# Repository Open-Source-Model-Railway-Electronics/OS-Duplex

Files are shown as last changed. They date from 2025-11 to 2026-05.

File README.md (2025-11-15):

# OS-Duplex

The OS-Duplex is a dual DCC accessory decoder designed for all types of turnout drives — from traditional solenoids to motor drives and relay modules for frog polarization.  
Each side (A and B) can operate independently or be linked together.

Optional relay sockets allow you to add point frog polarization, or use the same outputs to drive extra coils or motors.

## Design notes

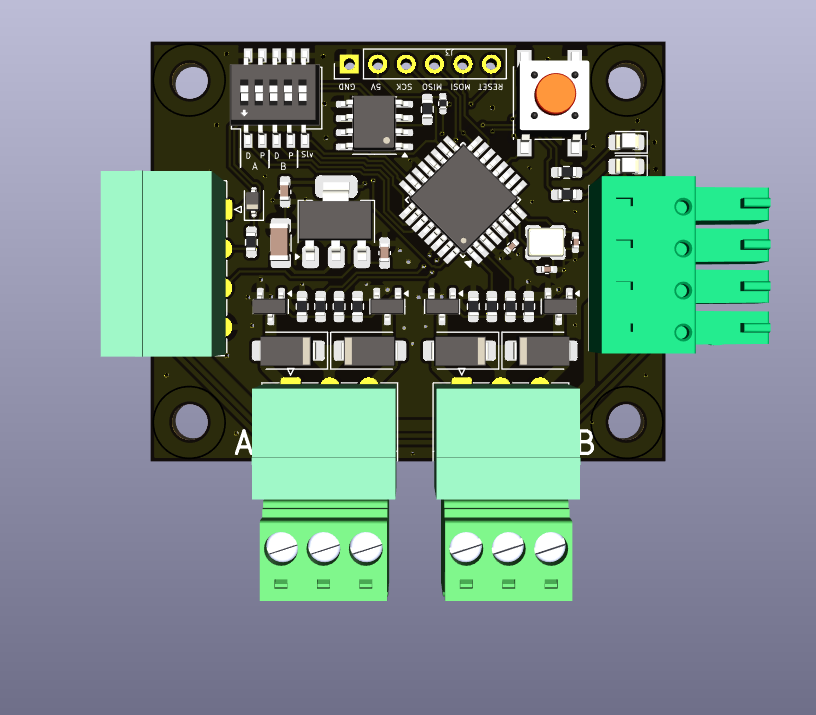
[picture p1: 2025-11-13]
hardware/OS-Duplex.png

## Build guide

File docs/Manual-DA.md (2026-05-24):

> 🌐 &nbsp; [🇬🇧 EN](Manual-EN.md) &nbsp;|&nbsp; [🇩🇪 DE](Manual-DE.md) &nbsp;|&nbsp; [🇫🇷 FR](Manual-FR.md) &nbsp;|&nbsp; [🇳🇱 NL](Manual-NL.md) &nbsp;|&nbsp; [🇪🇸 ES](Manual-ES.md) &nbsp;|&nbsp; [🇮🇹 IT](Manual-IT.md) &nbsp;|&nbsp; [🇵🇱 PL](Manual-PL.md) &nbsp;|&nbsp; [🇨🇿 CS](Manual-CS.md) &nbsp;|&nbsp; 🇩🇰 DA &nbsp;|&nbsp; [🇳🇴 NO](Manual-NO.md) &nbsp;|&nbsp; [🇸🇪 SV](Manual-SV.md) &nbsp;|&nbsp; [🇭🇺 HU](Manual-HU.md) &nbsp;|&nbsp; [🇵🇹 PT](Manual-PT.md)

# ⚙️ OS-Duplex Decoder-manual

**Dobbelt DCC-dekoder til solenoider, relæer og sporskiftemotorer**

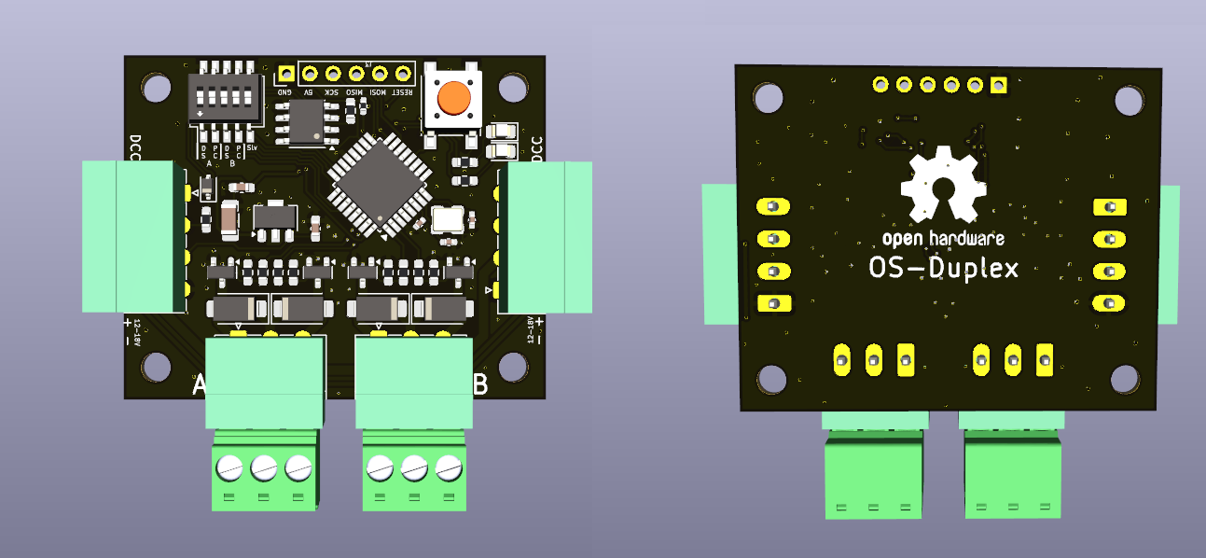
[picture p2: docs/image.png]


---

## 🔧 Introduktion

OS-Duplex er en dobbelt DCC-tilbehørsdekoder designet til alle typer sporskiftedrev — fra traditionelle solenoider til motordrev og relæmoduler til hjertestykke-polarisering.  
Hver side (A og B) kan fungere uafhængigt eller være koblet sammen.

Hver side kan fungere som enten:
- 🅰️ / 🅱️ to uafhængige enkeltudgange (hver med sin egen DCC-adresse), eller
- ⚙️ én kombineret dobbeltudgang til et toviklings- eller motordrevssporskifte.

Valgfrie relæstik giver mulighed for at tilføje sporskifte-hjertestykke-polarisering eller bruge de samme udgange til at drive ekstra spoler eller motorer.

---

## ⚡ Strømforsyning

OS-Duplex kræver en ekstern DC-strømforsyning på mellem 12 V og 18 V DC.  
⚠️ Polariteten er absolut. Overhold altid korrekte "+" og "–" forbindelser.

- Brug lavere spændinger (12 V) til sporskiftemotordrev  
- Brug højere spændinger (op til 18 V) til spoledrev

---

## 🧩 Tilslutninger

- 🔌 DCC IN – Indgang til DCC-kommandosignalet  
- ⚡ POW + / POW - – Strømindgange til hvert udgangssegment  
- ⚙️ OUT A / OUT B – Drevudgange til spoler, motorer eller relæer  
- 🔌 Gennemgangsstik – Du kan tilslutte flere Duplex-dekodere i de følgende stik  
- Du kan tilslutte op til fire relæmoduler

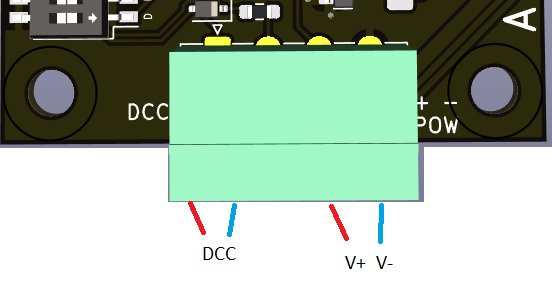
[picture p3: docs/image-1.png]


*Figur 1: Primære strømterminaler*

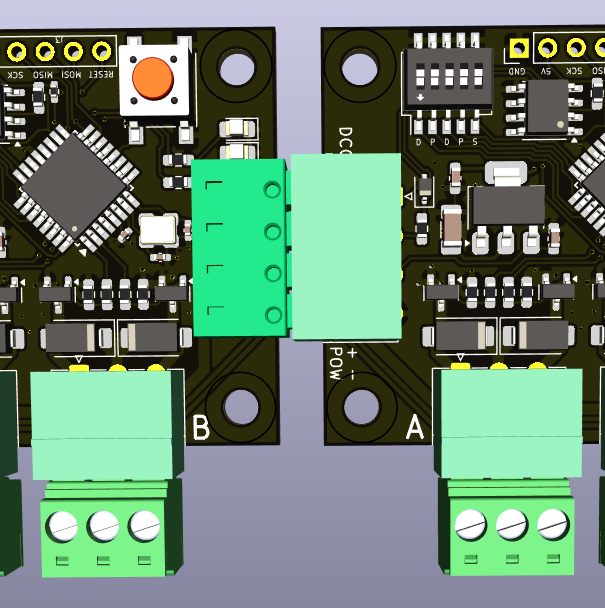
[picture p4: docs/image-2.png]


*Figur 2: 2 Duplex-dekodere kædet i serie*

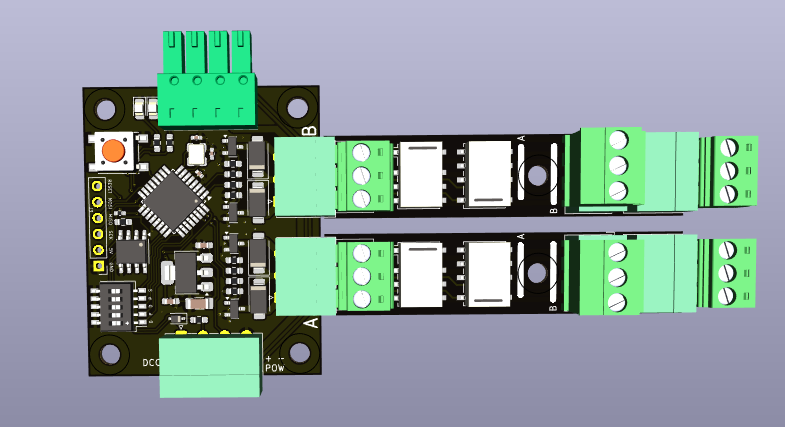
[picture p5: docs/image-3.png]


*Figur 3: 2 dobbelte relæmoduler tilsluttet*

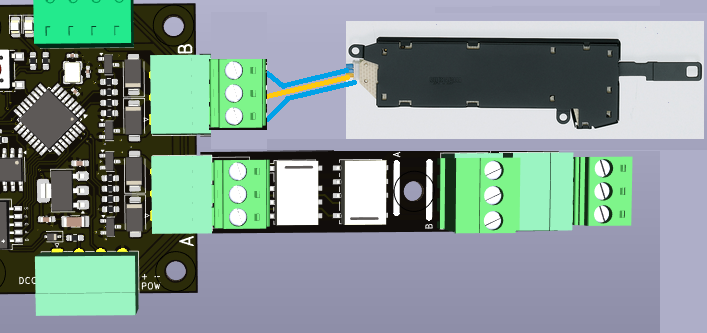
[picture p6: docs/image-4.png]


*Figur 4: Eksempel 1 — dobbelt spoledrev og dobbelt relæmodul*

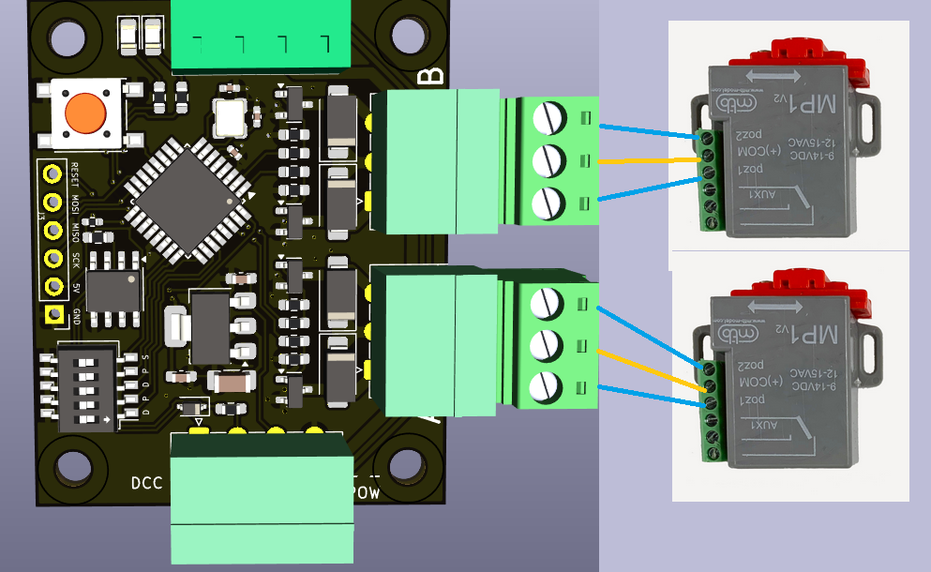
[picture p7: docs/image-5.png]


*Figur 5: Eksempel med 2x MTB MP-1*

---

## 🎚️ DIP-Switch-konfiguration

Fem DIP-switches definerer alle driftstilstande:

1️⃣ Udgang A – Tilstandsvalg: Enkelt / dobbelt udgang  
2️⃣ Udgang A – Pulstilstand: Puls (typisk spole) eller kontinuerlig (motor)  
3️⃣ Udgang B – Tilstandsvalg: Enkelt / dobbelt udgang  
4️⃣ Udgang B – Pulstilstand: Puls eller kontinuerlig  
5️⃣ Linkkontakt – Forbinder udgang B til udgang A (slavetilstand). Kun aktiv hvis A er indstillet til dobbelt tilstand

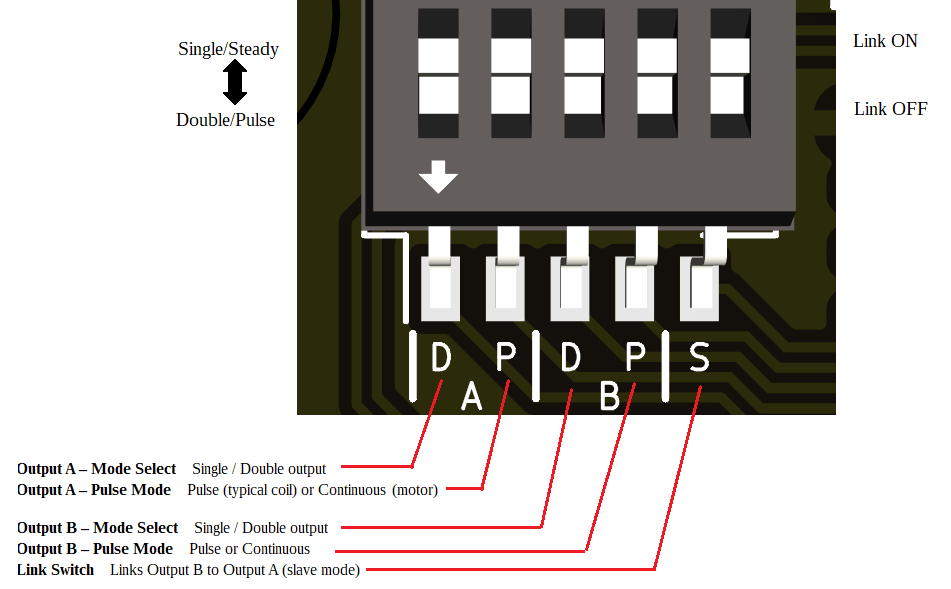
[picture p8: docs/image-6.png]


---

## ⚙️ Driftslogik

### 🅰️ Udgang A (primær)
- Fungerer som enkelt eller dobbelt udgang
- I dobbelt tilstand styrer én DCC-adresse begge udgange, uanset om de er pulset eller stabile
- I enkelt tilstand bruger hver udgang sin egen adresse

### 🅱️ Udgang B (sekundær)
- Kan køre uafhængigt som A eller som slave til A
- I koblet drift kan B automatisk håndtere hjertestykke-polarisering; det skifter relæerne og sporskiftemotoren i en bestemt rækkefølge for at forhindre kortslutninger:
    1. Afspænd hjertestykket
    2. Skift sporskiftet
    3. Genspænd hjertestykket med modsat polaritet

Denne timing understøtter Electrofrog- og Unifrog-anlæg

---

## 🔗 Slavetilstands-udvidelser

### Signaltilstand

Når linket er aktiveret mellem udgangene, ændrer udgang B adfærd afhængigt af A's tilstand:
- Hvis A er Enkelt + Puls, accepterer dekoderen DCC EXT-kommandoer til 4-lampe-signaler  
- Begge udgange fungerer sammen som en miniature-signalstyreenhed  
- OS-Duplex har ikke noget begreb om faste indstillinger, aspekter eller forindstillinger, hvad angår signaler. I stedet bruger vi DCC EXT-kommandoer, hvormed vi kan sende en værdi på 0–255 til dekoderen.

Værdien fungerer binært. 255 har den binære værdi `1111 1111`. Den høje nibble (de første 4 bits) angiver hvilke LED'er der skal blinke; den lave nibble (de sidste 4 bits) angiver hvilke lys der skal være tændt eller slukket. Når et lys er indstillet til at blinke via den høje nibble, skal den tilsvarende bit i den lave nibble være `0`. **For eksempel, når kun de første to lys skal blinke, det tredje lys er slukket, og det fjerde lys er tændt: værdien er `1100 0001` = 193 decimal.**

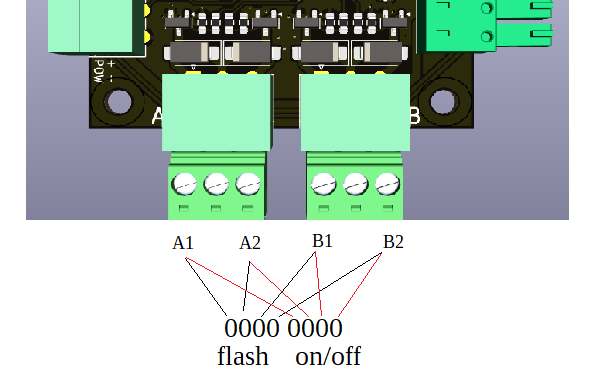
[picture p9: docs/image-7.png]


Det software, du bruger til dit modeljernbaneanlæg, skal knytte signalaspekterne til DCC EXT-værdier. Skriv den binære værdi ned for hvert ønsket aspekt og beregn derefter den decimale ækvivalent. Windows' indbyggede Lommeregner-app kan hjælpe — skift den til **Programmør**-tilstand først.

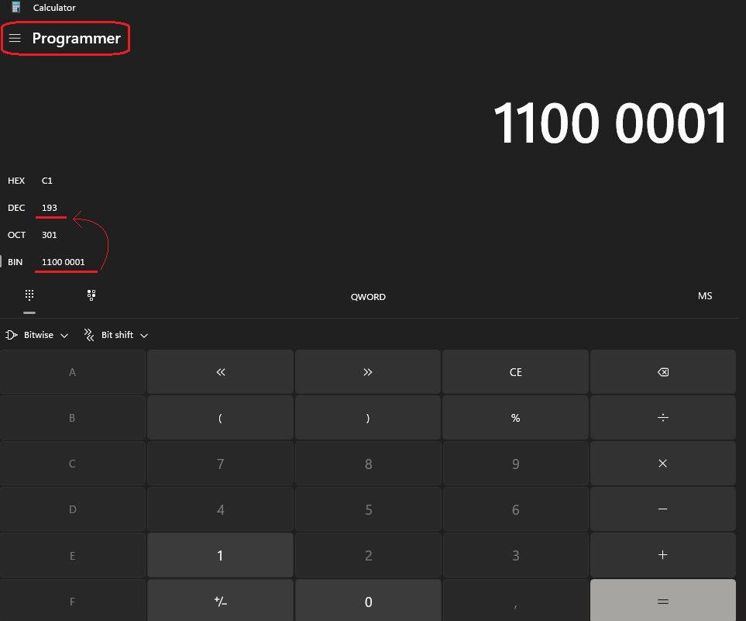
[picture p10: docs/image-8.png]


Som eksempel tager vi et hollandsk hovedlinjessignal. Vi forbinder grøn til A1, gul til A2, rød til B1 og nummerboksen til B2. Lilla er den fælles +-ledning.

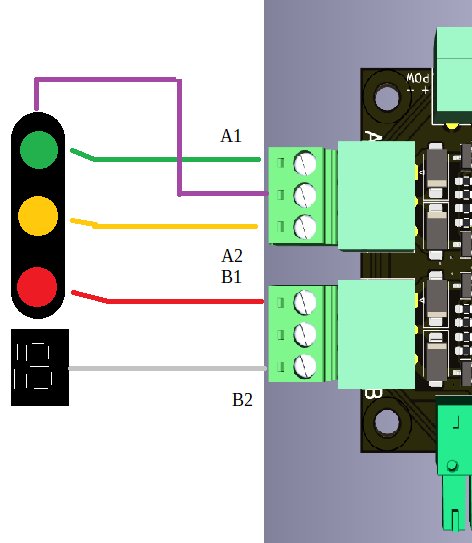
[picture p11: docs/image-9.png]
alternativ tekst


Dette signal bruger disse aspekter.

| Aspekt | Lamper (G/Y/R/W) | Høj nibble (blinkbits) | Lav nibble (tændt/slukket-bits) | Decimal |
|---|---|---|---|---|
| Stop | R | 0000 | 0100 | 4 |
| Kør | G | 0000 | 0001 | 1 |
| Forsigtig / Forvent stop | Y | 0000 | 0010 | 2 |
| Kør på sigt (Y blinker) | Y (blink) | 0010 | 0000 | 32 |
| Afvigende / hastighedsrute (G blinker) | G (blink) | 0001 | 0000 | 16 |
| Hastighed angivet ved dette signal (G blinker + W TÆNDt) | G (blink) + W TÆNDt | 0001 | 1000 | 24 |
| Tilkørsel med hastighed ved næste signal (Y + W TÆNDt) | Y TÆNDt + W TÆNDt | 0000 | 1010 | 10 |

---

## 💡 Tekniske noter

- Kompatibel med Roco, NMRA og udvidet DCC-adressering
- Hver udgang kan sikkert levere strøm til standard sporskiftespoler eller små motorer
- EEPROM gemmer seneste konfiguration og adresser
- Firmware understøtter adresseindlæring via DCC-kommando eller knapindgang (hvis implementeret)

---

## 🧰 Sikkerhed og anbefalinger

- Verificer altid korrekt forsyningspolaritet inden idriftsætning
- Overskrid ikke 18 V DC
- Sørg for tilstrækkelig afstand ved drift af fire højstrømsrelæer samtidigt
- Brug en passende DC-forsyning med strømkapacitet, der matcher din sporskiftetype

---

## Bilag A: DIP-switch-kombinationer

### Individuelle udgange        

| DIP-switches | Beskrivelse |
|---|---|
| 00000 | A = Dobbelt puls, B = Dobbelt puls |
| 00010 | A = Dobbelt puls, B = Dobbelt stabil |
| 00110 | A = Dobbelt puls, B = Enkelt stabil |
| 01000 | A = Dobbelt stabil, B = Dobbelt puls |
| 01010 | A = Dobbelt stabil, B = Dobbelt stabil |
| 01110 | A = Dobbelt stabil, B = Enkelt stabil |
| 11000 | A = Enkelt stabil, B = Dobbelt puls |
| 11010 | A = Enkelt stabil, B = Dobbelt stabil |
| 11110 | A = Enkelt stabil, B = Enkelt stabil |

### Udgang B koblet til udgang A

| DIP-switches | Beskrivelse |
|---|---|
| 00001 | A = Dobbelt puls, B = Dobbelt relæ |
| 00101 | A = Dobbelt puls, B = Enkelt relæ |
| 01001 | A = Dobbelt stabil, B = Dobbelt relæ |
| 01101 | A = Dobbelt stabil, B = Enkelt relæ |
| 10001 | Signaltilstand |

---

📘 *Slutning på manual*

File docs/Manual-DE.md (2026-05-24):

> 🌐 &nbsp; [🇬🇧 EN](Manual-EN.md) &nbsp;|&nbsp; 🇩🇪 DE &nbsp;|&nbsp; [🇫🇷 FR](Manual-FR.md) &nbsp;|&nbsp; [🇳🇱 NL](Manual-NL.md) &nbsp;|&nbsp; [🇪🇸 ES](Manual-ES.md) &nbsp;|&nbsp; [🇮🇹 IT](Manual-IT.md) &nbsp;|&nbsp; [🇵🇱 PL](Manual-PL.md) &nbsp;|&nbsp; [🇨🇿 CS](Manual-CS.md) &nbsp;|&nbsp; [🇩🇰 DA](Manual-DA.md) &nbsp;|&nbsp; [🇳🇴 NO](Manual-NO.md) &nbsp;|&nbsp; [🇸🇪 SV](Manual-SV.md) &nbsp;|&nbsp; [🇭🇺 HU](Manual-HU.md) &nbsp;|&nbsp; [🇵🇹 PT](Manual-PT.md)

# ⚙️ OS-Duplex Decoder Handbuch

**Dualer DCC-Decoder für Magnetartikel, Relais und Weichenmotoren**



---

## 🔧 Einführung

Der OS-Duplex ist ein dualer DCC-Zubehördecoder für alle Arten von Weichenantrieben — von traditionellen Magnetartikeln über Motorantriebe bis hin zu Relaismodulen für die Herzstück-Polarisierung.  
Jede Seite (A und B) kann unabhängig betrieben oder miteinander verbunden werden.

Jede Seite kann entweder als:
- 🅰️ / 🅱️ zwei unabhängige Einzelausgänge (jeweils mit eigener DCC-Adresse), oder
- ⚙️ ein kombinierter Doppelausgang für einen Doppelspulen- oder Motorantrieb-Weiche

fungieren.

Optionale Relais-Sockel ermöglichen die Herzstück-Polarisierung oder den Betrieb zusätzlicher Spulen oder Motoren über dieselben Ausgänge.

---

## ⚡ Stromversorgung

Der OS-Duplex benötigt eine externe DC-Stromversorgung zwischen 12 V und 18 V DC.  
⚠️ Die Polarität ist absolut. Beachte stets die korrekte „+" und „–" Verbindung.

- Niedrigere Spannungen (12 V) für Motorantriebe verwenden  
- Höhere Spannungen (bis 18 V) für Magnetartikelantriebe verwenden

---

## 🧩 Anschlüsse

- 🔌 DCC IN – Eingang für das DCC-Befehlssignal  
- ⚡ POW + / POW - – Stromversorgungseingänge für jeden Ausgangsbereich  
- ⚙️ OUT A / OUT B – Antriebsausgänge für Spulen, Motoren oder Relais  
- 🔌 Durchschleif-Stecker – Weitere Duplex-Decoder können in die folgenden Buchsen gesteckt werden  
- Es können bis zu vier Relaismodule eingesteckt werden



*Abbildung 1: Hauptstromklemmen*



*Abbildung 2: 2 in Reihe geschaltete Duplex-Decoder*



*Abbildung 3: 2 doppelte Relaismodule eingesteckt*



*Abbildung 4: Beispiel 1 Doppelspulenantrieb und doppeltes Relaismodul*



*Abbildung 5: Beispiel mit 2x MTB MP-1*

---

## 🎚️ DIP-Schalter-Konfiguration

Fünf DIP-Schalter definieren alle Betriebsmodi:

1️⃣ Ausgang A – Modusauswahl: Einzel- / Doppelausgang  
2️⃣ Ausgang A – Impulsmodus: Impuls (typisch für Spule) oder Dauerbetrieb (Motor)  
3️⃣ Ausgang B – Modusauswahl: Einzel- / Doppelausgang  
4️⃣ Ausgang B – Impulsmodus: Impuls oder Dauerbetrieb  
5️⃣ Verbindungsschalter – Verbindet Ausgang B mit Ausgang A (Slave-Modus). Nur aktiv, wenn A auf Doppelmodus eingestellt ist



---

## ⚙️ Betriebslogik

### 🅰️ Ausgang A (Primär)
- Funktioniert als Einzel- oder Doppelausgang
- Im Doppelmodus steuert eine DCC-Adresse beide Ausgänge, egal ob gepulst oder dauerhaft
- Im Einzelmodus verwendet jeder Ausgang seine eigene Adresse

### 🅱️ Ausgang B (Sekundär)
- Kann wie A unabhängig betrieben oder als Slave zu A betrieben werden
- Im verbundenen Betrieb kann B die Herzstück-Polarisierung automatisch übernehmen; er schaltet die Relais und den Weichenmotor in einer bestimmten Reihenfolge, um Kurzschlüsse zu vermeiden:
    1. Herzstück stromlos schalten
    2. Weiche stellen
    3. Herzstück mit umgekehrter Polarität wieder bestromen

Diese Schaltsequenz unterstützt Electrofrog- und Unifrog-Anlagen

---

## 🔗 Slave-Modus-Erweiterungen

### Signalmodus

Wenn die Verbindung zwischen den Ausgängen aktiviert ist, ändert Ausgang B sein Verhalten abhängig vom Modus von A:
- Wenn A Einzel + Impuls ist, akzeptiert der Decoder DCC EXT-Befehle für 4-Lampen-Signale  
- Beide Ausgänge agieren zusammen als miniaturisierter Signalregler  
- Der Duplex hat kein Konzept von festen Einstellungen, Begriffen oder Voreinstellungen für Signale. Stattdessen werden DCC EXT-Befehle verwendet, mit denen ein Wert von 0–255 an den Decoder übertragen werden kann.

Der Wert funktioniert binär. 255 hat den Binärwert `1111 1111`. Das obere Halbbyte (erste 4 Bits) gibt an, welche LEDs blinken sollen; das untere Halbbyte (letzte 4 Bits) gibt an, welche Lichter ein- oder ausgeschaltet sein sollen. Wenn ein Licht über das obere Halbbyte auf Blinken gesetzt wird, muss das entsprechende Bit im unteren Halbbyte `0` sein. **Wenn beispielsweise nur die ersten beiden Lichter blinken sollen, das dritte Licht aus und das vierte Licht an ist: Der Wert lautet `1100 0001` = 193 dezimal.**



Die Software, die du für deine Modellbahnanlage verwendest, muss die Signalbegriffe mit DCC EXT-Werten verknüpfen. Notiere den Binärwert für jeden gewünschten Begriff und berechne dann das Dezimaläquivalent. Der eingebaute Taschenrechner von Windows kann dabei helfen — stelle ihn zuerst in den **Programmierer**-Modus um.



Als Beispiel nehmen wir ein niederländisches Hauptstreckensignal. Wir verbinden Grün mit A1, Gelb mit A2, Rot mit B1 und den Nummernkasten mit B2. Lila ist die gemeinsame +-Leitung.



Dieses Signal verwendet folgende Begriffe:

| Begriff | Lampen (G/Y/R/W) | Oberes Halbbyte (Blinkbits) | Unteres Halbbyte (Ein/Aus-Bits) | Dezimal |
|---|---|---|---|---|
| Halt | R | 0000 | 0100 | 4 |
| Fahrt | G | 0000 | 0001 | 1 |
| Langsamfahrt / Halt erwarten | Y | 0000 | 0010 | 2 |
| Fahrt auf Sicht (Y blinkend) | Y (blink) | 0010 | 0000 | 32 |
| Abweichende Fahrt / Geschwindigkeitsroute (G blinkend) | G (blink) | 0001 | 0000 | 16 |
| Geschwindigkeit am Signal angezeigt (G blinkend + W EIN) | G (blink) + W EIN | 0001 | 1000 | 24 |
| Heranfahren mit Geschwindigkeit am nächsten Signal (Y + W EIN) | Y EIN + W EIN | 0000 | 1010 | 10 |

---

## 💡 Technische Hinweise

- Kompatibel mit Roco-, NMRA- und erweiterter DCC-Adressierung
- Jeder Ausgang kann standardmäßige Weichenspulen oder kleine Motoren sicher versorgen
- EEPROM speichert die letzte Konfiguration und Adressen
- Firmware unterstützt Adress-Einlernen per DCC-Befehl oder Taste (sofern implementiert)

---

## 🧰 Sicherheit & Empfehlungen

- Stets die korrekte Versorgungspolärität prüfen, bevor die Stromversorgung eingeschaltet wird
- 18 V DC nicht überschreiten
- Ausreichend Abstand einhalten, wenn vier Hochstromrelais gleichzeitig betrieben werden
- Ein geeignetes DC-Netzteil mit ausreichender Stromkapazität für den jeweiligen Weichentyp verwenden

---

## Anhang A, DIP-Schalter-Kombinationen

### Individuelle Ausgänge

| DIP-Schalter | Beschreibung |
|---|---|
| 00000 | A = Doppelimpuls, B = Doppelimpuls |
| 00010 | A = Doppelimpuls, B = Doppeldauerbetrieb |
| 00110 | A = Doppelimpuls, B = Einzeldauerbetrieb |
| 01000 | A = Doppeldauerbetrieb, B = Doppelimpuls |
| 01010 | A = Doppeldauerbetrieb, B = Doppeldauerbetrieb |
| 01110 | A = Doppeldauerbetrieb, B = Einzeldauerbetrieb |
| 11000 | A = Einzeldauerbetrieb, B = Doppelimpuls |
| 11010 | A = Einzeldauerbetrieb, B = Doppeldauerbetrieb |
| 11110 | A = Einzeldauerbetrieb, B = Einzeldauerbetrieb |

### Ausgang B mit Ausgang A verbunden

| DIP-Schalter | Beschreibung |
|---|---|
| 00001 | A = Doppelimpuls, B = Doppelrelais |
| 00101 | A = Doppelimpuls, B = Einzelrelais |
| 01001 | A = Doppeldauerbetrieb, B = Doppelrelais |
| 01101 | A = Doppeldauerbetrieb, B = Einzelrelais |
| 10001 | Signalmodus |

---

📘 *Ende des Handbuchs*

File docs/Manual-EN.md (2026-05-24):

> 🌐 &nbsp; 🇬🇧 EN &nbsp;|&nbsp; [🇩🇪 DE](Manual-DE.md) &nbsp;|&nbsp; [🇫🇷 FR](Manual-FR.md) &nbsp;|&nbsp; [🇳🇱 NL](Manual-NL.md) &nbsp;|&nbsp; [🇪🇸 ES](Manual-ES.md) &nbsp;|&nbsp; [🇮🇹 IT](Manual-IT.md) &nbsp;|&nbsp; [🇵🇱 PL](Manual-PL.md) &nbsp;|&nbsp; [🇨🇿 CS](Manual-CS.md) &nbsp;|&nbsp; [🇩🇰 DA](Manual-DA.md) &nbsp;|&nbsp; [🇳🇴 NO](Manual-NO.md) &nbsp;|&nbsp; [🇸🇪 SV](Manual-SV.md) &nbsp;|&nbsp; [🇭🇺 HU](Manual-HU.md) &nbsp;|&nbsp; [🇵🇹 PT](Manual-PT.md)

# ⚙️ OS-Duplex Decoder Manual

**Dual DCC decoder for solenoids, relays and turnout motors**



---

## 🔧 Introduction

The OS-Duplex is a dual DCC accessory decoder designed for all types of turnout drives — from traditional solenoids to motor drives and relay modules for frog polarization.  
Each side (A and B) can operate independently or be linked together.

Every side can act as either:
- 🅰️ / 🅱️ two independent single outputs (each with its own DCC address), or
- ⚙️ one combined double output for a twin-coil or motor drive turnout.

Optional relay sockets allow you to add point frog polarization, or use the same outputs to drive extra coils or motors.

---

## ⚡ Power Supply

The OS-Duplex requires an external DC power supply between 12 V and 18 V DC.  
⚠️ The polarity is absolute. Always observe correct “+” and “–” connections.

- Use lower voltages (12 V) for point motor drives  
- Use higher voltages (up to 18 V) for coil drives

---

## 🧩 Connections

- 🔌 DCC IN – Input for the DCC command signal  
- ⚡ POW + / POW - – Power inputs for each output section  
- ⚙️ OUT A / OUT B – Drive outputs for coils, motors, or relays  
- 🔌 Pass-Through Connectors – You can plug in more Duplex decoders in the following sockets  
- You can plug in up to four relay modules



*Figure 1: Main power terminals*



*Figure 2: 2 Duplex decoders daisy chained*



*Figure 3: 2 double relay modules plugged in*



*Figure 4: Example 1 Double Coil Drive and Double relay module*



*Figure 5: Example with 2x MTB MP-1*

---

## 🎚️ DIP-Switch Configuration

Five DIP switches define all operating modes:

1️⃣ Output A – Mode Select: Single / Double output  
2️⃣ Output A – Pulse Mode: Pulse (typical coil) or Continuous (motor)  
3️⃣ Output B – Mode Select: Single / Double output  
4️⃣ Output B – Pulse Mode: Pulse or Continuous  
5️⃣ Link Switch – Links Output B to Output A (slave mode). Only active if A is set to Double mode



---

## ⚙️ Operating Logic

### 🅰️ Output A (Primary)
- Works as single or double output
- In double mode, one DCC address controls both output, whether they are pulsed or steady
- In single mode, each output uses its own address

### 🅱️ Output B (Secondary)
- May run independently like A or as slave to A
- In linked operation, B can automatically handle frog polarization; it switches the relays and point motor in a specific sequence to prevent shorts from occurring:
    1. De-energize frog
    2. Switch turnout
    3. Re-energize frog with opposite polarity

This timing supports Electrofrog and Uni-frog layouts

---

## 🔗 Slave Mode Extensions

### Signal mode

When the link is enabled between the outputs, Output B changes behavior depending on A’s mode:
- If A is Single + Pulse, the decoder accepts DCC Extended commands for 4-lamp signals  
- Both outputs act together as a miniature signal controller  
- The Duplex has no concept of fixed settings, aspects or pre-sets when it comes to signals. Instead we use the DCC Extended commands with which we can transmit a value of 0–255 to the decoder.

The value works in binary. 255 has a binary value of `1111 1111`. The high nibble (first 4 bits) tells which LEDs should flash; the low nibble (last 4 bits) tells which lights should be on or off. When a light is set to flash via the high nibble, the corresponding bit in the low nibble must be `0`. **For example, when only the first two lights should flash, the third light is off, and the fourth light is on: the value is `1100 0001` = 193 decimal.**



The software you use for your model railway layout needs to link the signal aspects to DCC Extended values. Write down the binary value for each desired aspect and then calculate the decimal equivalent. Windows' built-in Calculator app can help — switch it to **Programmer** mode first.



As example we take a Dutch main Line signal. We connect green to A1, yellow to A2, red to B1 and the number box to B2. Purple is the common + lead



This signal uses these aspects. 

| Aspect | Lamps (G/Y/R/W) | High nibble (flash bits) | Low nibble (on/off bits) | Decimal |
|---|---|---|---|---|
| Stop | R | 0000 | 0100 | 4 |
| Proceed | G | 0000 | 0001 | 1 |
| Caution / Expect stop | Y | 0000 | 0010 | 2 |
| Drive on sight (Y flashing) | Y (flash) | 0010 | 0000 | 32 |
| Diverging / speed route (G flashing) | G (flash) | 0001 | 0000 | 16 |
| Speed indicated at this signal (G flashing + W ON) | G (flash) + W ON | 0001 | 1000 | 24 |
| Approach with speed at next signal (Y + W ON) | Y ON + W ON | 0000 | 1010 | 10 |

---

## 💡 Technical Notes

- Compatible with Roco, NMRA, and extended DCC addressing
- Each output can safely source standard turnout coils or small motors
- EEPROM stores last configuration and addresses
- Firmware supports address learning via DCC command or button input (if implemented)

---

## 🧰 Safety & Recommendations

- Always verify correct supply polarity before powering
- Do not exceed 18 V DC
- Keep adequate spacing if driving four high-current relays simultaneously
- Use a proper DC supply with current capability matching your turnout type

---

## Appendix A, DIP switch combinations

### Individual outputs        

| Dipswitches | Description |
|---|---|
| 00000 | A = Double Pulse, B = Double Pulse |
| 00010 | A = Double Pulse, B = Double Steady |
| 00110 | A = Double Pulse, B = Single Steady |
| 01000 | A = Double Steady, B = Double Pulse |
| 01010 | A = Double Steady, B = Double Steady |
| 01110 | A = Double Steady, B = Single Steady |
| 11000 | A = Single Steady, B = Double Pulse |
| 11010 | A = Single Steady, B = Double Steady |
| 11110 | A = Single Steady, B = Single Steady |

### Output B linked to output A

| Dipswitches | Description |
|---|---|
| 00001 | A = Double Pulse, B = Double Relay |
| 00101 | A = Double Pulse, B = Single Relay |
| 01001 | A = Double Steady, B = Double Relay |
| 01101 | A = Double Steady, B = Single Relay |
| 10001 | Signal mode |

---

📘 *End of Manual*

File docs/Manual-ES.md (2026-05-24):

> 🌐 &nbsp; [🇬🇧 EN](Manual-EN.md) &nbsp;|&nbsp; [🇩🇪 DE](Manual-DE.md) &nbsp;|&nbsp; [🇫🇷 FR](Manual-FR.md) &nbsp;|&nbsp; [🇳🇱 NL](Manual-NL.md) &nbsp;|&nbsp; 🇪🇸 ES &nbsp;|&nbsp; [🇮🇹 IT](Manual-IT.md) &nbsp;|&nbsp; [🇵🇱 PL](Manual-PL.md) &nbsp;|&nbsp; [🇨🇿 CS](Manual-CS.md) &nbsp;|&nbsp; [🇩🇰 DA](Manual-DA.md) &nbsp;|&nbsp; [🇳🇴 NO](Manual-NO.md) &nbsp;|&nbsp; [🇸🇪 SV](Manual-SV.md) &nbsp;|&nbsp; [🇭🇺 HU](Manual-HU.md) &nbsp;|&nbsp; [🇵🇹 PT](Manual-PT.md)

# ⚙️ Manual del Decodificador OS-Duplex

**Decodificador DCC dual para solenoides, relés y motores de aguja**



---

## 🔧 Introducción

El OS-Duplex es un decodificador de accesorios DCC dual diseñado para todo tipo de accionamientos de agujas: desde solenoides tradicionales hasta accionamientos por motor y módulos de relé para polarización de frog.  
Cada lado (A y B) puede funcionar de forma independiente o estar vinculado entre sí.

Cada lado puede actuar como:
- 🅰️ / 🅱️ dos salidas individuales independientes (cada una con su propia dirección DCC), o
- ⚙️ una salida doble combinada para una aguja de doble bobina o accionamiento por motor.

Las tomas de relé opcionales permiten añadir polarización de frog, o usar las mismas salidas para accionar bobinas o motores adicionales.

---

## ⚡ Alimentación

El OS-Duplex requiere una fuente de alimentación DC externa de entre 12 V y 18 V DC.  
⚠️ La polaridad es absoluta. Respete siempre las conexiones correctas de "+" y "–".

- Utilice tensiones más bajas (12 V) para accionamientos por motor de aguja  
- Utilice tensiones más altas (hasta 18 V) para accionamientos por bobina

---

## 🧩 Conexiones

- 🔌 DCC IN – Entrada para la señal de comando DCC  
- ⚡ POW + / POW - – Entradas de alimentación para cada sección de salida  
- ⚙️ OUT A / OUT B – Salidas de accionamiento para bobinas, motores o relés  
- 🔌 Conectores de paso directo – Puede enchufar más decodificadores Duplex en las tomas siguientes  
- Puede enchufar hasta cuatro módulos de relé



*Figura 1: Bornes de alimentación principales*



*Figura 2: 2 decodificadores Duplex en cadena*



*Figura 3: 2 módulos de doble relé enchufados*



*Figura 4: Ejemplo 1 — Accionamiento de doble bobina y módulo de doble relé*



*Figura 5: Ejemplo con 2x MTB MP-1*

---

## 🎚️ Configuración de Microinterruptores DIP

Cinco microinterruptores DIP definen todos los modos de funcionamiento:

1️⃣ Salida A – Selección de modo: salida individual / doble  
2️⃣ Salida A – Modo de impulso: Impulso (bobina típica) o Continuo (motor)  
3️⃣ Salida B – Selección de modo: salida individual / doble  
4️⃣ Salida B – Modo de impulso: Impulso o Continuo  
5️⃣ Interruptor de enlace – Vincula la Salida B a la Salida A (modo esclavo). Solo activo si A está configurada en modo doble



---

## ⚙️ Lógica de Funcionamiento

### 🅰️ Salida A (Principal)
- Funciona como salida individual o doble
- En modo doble, una dirección DCC controla ambas salidas, ya sean por impulso o continuas
- En modo individual, cada salida usa su propia dirección

### 🅱️ Salida B (Secundaria)
- Puede funcionar de forma independiente como A o como esclava de A
- En funcionamiento enlazado, B puede gestionar automáticamente la polarización de frog; conmuta los relés y el motor de aguja en una secuencia específica para evitar cortocircuitos:
    1. Desactivar el frog
    2. Conmutar la aguja
    3. Reactivar el frog con polaridad inversa

Este temporizado es compatible con agujas Electrofrog y Unifrog

---

## 🔗 Extensiones del Modo Esclavo

### Modo de señal

Cuando el enlace entre salidas está habilitado, la Salida B cambia su comportamiento según el modo de A:
- Si A es Individual + Impulso, el decodificador acepta comandos DCC Extended para señales de 4 luces  
- Ambas salidas actúan conjuntamente como un controlador de señal en miniatura  
- El Duplex no tiene concepto de ajustes fijos, aspectos o preajustes en lo referente a señales. En su lugar se utilizan los comandos DCC Extended con los que se puede transmitir un valor de 0 a 255 al decodificador.

El valor funciona en binario. 255 tiene un valor binario de `1111 1111`. El nibble alto (primeros 4 bits) indica qué LED deben parpadear; el nibble bajo (últimos 4 bits) indica qué luces deben estar encendidas o apagadas. Cuando una luz se configura para parpadear mediante el nibble alto, el bit correspondiente en el nibble bajo debe ser `0`. **Por ejemplo, cuando solo las dos primeras luces deben parpadear, la tercera luz está apagada y la cuarta luz está encendida: el valor es `1100 0001` = 193 en decimal.**



El software que utilice para su maqueta de ferrocarril debe vincular los aspectos de señal con los valores DCC Extended. Anote el valor binario de cada aspecto deseado y calcule su equivalente decimal. La aplicación Calculadora integrada en Windows puede ayudar — cámbiela primero al modo **Programador**.



Como ejemplo tomamos una señal de línea principal neerlandesa. Conectamos el verde a A1, el amarillo a A2, el rojo a B1 y el cuadro de número a B2. El morado es el conductor común +.

texto alternativo

Esta señal utiliza los siguientes aspectos.

| Aspecto | Lámparas (V/A/R/B) | Nibble alto (bits de parpadeo) | Nibble bajo (bits on/off) | Decimal |
|---|---|---|---|---|
| Parada | R | 0000 | 0100 | 4 |
| Circulación libre | G | 0000 | 0001 | 1 |
| Precaución / Espere parada | Y | 0000 | 0010 | 2 |
| Circular a la vista (Y parpadeante) | Y (parpadeo) | 0010 | 0000 | 32 |
| Desvío / ruta de velocidad (G parpadeante) | G (parpadeo) | 0001 | 0000 | 16 |
| Velocidad indicada en esta señal (G parpadeante + B encendido) | G (parpadeo) + W ON | 0001 | 1000 | 24 |
| Aproximación con velocidad en la siguiente señal (A + B encendidos) | Y ON + W ON | 0000 | 1010 | 10 |

---

## 💡 Notas Técnicas

- Compatible con direccionamiento DCC de Roco, NMRA y extendido
- Cada salida puede accionar de forma segura bobinas de aguja estándar o motores pequeños
- La EEPROM almacena la última configuración y las direcciones
- El firmware admite aprendizaje de direcciones mediante comando DCC o entrada por botón (si está implementado)

---

## 🧰 Seguridad y Recomendaciones

- Verifique siempre la polaridad correcta de la fuente antes de conectar
- No supere los 18 V DC
- Mantenga el espaciado adecuado al accionar cuatro relés de alta corriente simultáneamente
- Utilice una fuente DC adecuada con capacidad de corriente acorde al tipo de aguja

---

## Apéndice A, Combinaciones de microinterruptores DIP

### Salidas individuales        

| Microinterruptores | Descripción |
|---|---|
| 00000 | A = Impulso doble, B = Impulso doble |
| 00010 | A = Impulso doble, B = Continuo doble |
| 00110 | A = Impulso doble, B = Continuo individual |
| 01000 | A = Continuo doble, B = Impulso doble |
| 01010 | A = Continuo doble, B = Continuo doble |
| 01110 | A = Continuo doble, B = Continuo individual |
| 11000 | A = Continuo individual, B = Impulso doble |
| 11010 | A = Continuo individual, B = Continuo doble |
| 11110 | A = Continuo individual, B = Continuo individual |

### Salida B vinculada a salida A

| Microinterruptores | Descripción |
|---|---|
| 00001 | A = Impulso doble, B = Relé doble |
| 00101 | A = Impulso doble, B = Relé individual |
| 01001 | A = Continuo doble, B = Relé doble |
| 01101 | A = Continuo doble, B = Relé individual |
| 10001 | Modo de señal |

---

📘 *Fin del Manual*

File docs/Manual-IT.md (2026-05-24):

> 🌐 &nbsp; [🇬🇧 EN](Manual-EN.md) &nbsp;|&nbsp; [🇩🇪 DE](Manual-DE.md) &nbsp;|&nbsp; [🇫🇷 FR](Manual-FR.md) &nbsp;|&nbsp; [🇳🇱 NL](Manual-NL.md) &nbsp;|&nbsp; [🇪🇸 ES](Manual-ES.md) &nbsp;|&nbsp; 🇮🇹 IT &nbsp;|&nbsp; [🇵🇱 PL](Manual-PL.md) &nbsp;|&nbsp; [🇨🇿 CS](Manual-CS.md) &nbsp;|&nbsp; [🇩🇰 DA](Manual-DA.md) &nbsp;|&nbsp; [🇳🇴 NO](Manual-NO.md) &nbsp;|&nbsp; [🇸🇪 SV](Manual-SV.md) &nbsp;|&nbsp; [🇭🇺 HU](Manual-HU.md) &nbsp;|&nbsp; [🇵🇹 PT](Manual-PT.md)

# ⚙️ Manuale OS-Duplex Decoder

**Decoder DCC doppio per solenoidi, relè e motori di scambio**



---

## 🔧 Introduzione

L'OS-Duplex è un decoder DCC per accessori a doppio canale progettato per tutti i tipi di azionamento degli scambi — dai tradizionali solenoidi ai motori e ai moduli relè per la polarizzazione del frog.  
Ogni canale (A e B) può funzionare in modo indipendente o essere collegato all'altro.

Ogni canale può operare come:
- 🅰️ / 🅱️ due uscite singole indipendenti (ciascuna con il proprio indirizzo DCC), oppure
- ⚙️ un'unica uscita doppia combinata per uno scambio a doppia bobina o a motore.

I connettori relè opzionali consentono di aggiungere la polarizzazione del frog dello scambio, oppure di usare le stesse uscite per azionare bobine o motori aggiuntivi.

---

## ⚡ Alimentazione

L'OS-Duplex richiede un'alimentazione DC esterna compresa tra 12 V e 18 V DC.  
⚠️ La polarità è assoluta. Rispettare sempre il corretto collegamento "+" e "–".

- Usare tensioni più basse (12 V) per i motori di scambio  
- Usare tensioni più alte (fino a 18 V) per l'azionamento delle bobine

---

## 🧩 Connessioni

- 🔌 DCC IN – Ingresso per il segnale di comando DCC  
- ⚡ POW + / POW - – Ingressi di alimentazione per ciascuna sezione di uscita  
- ⚙️ OUT A / OUT B – Uscite di azionamento per bobine, motori o relè  
- 🔌 Connettori pass-through – È possibile collegare ulteriori decoder Duplex ai connettori seguenti  
- È possibile collegare fino a quattro moduli relè



*Figura 1: Morsetti di alimentazione principali*



*Figura 2: 2 decoder Duplex collegati a cascata*



*Figura 3: 2 moduli relè doppi inseriti*



*Figura 4: Esempio 1 — Azionamento a doppia bobina e modulo relè doppio*



*Figura 5: Esempio con 2x MTB MP-1*

---

## 🎚️ Configurazione DIP-Switch

Cinque DIP switch definiscono tutte le modalità operative:

1️⃣ Uscita A – Selezione modalità: uscita singola / doppia  
2️⃣ Uscita A – Modalità impulso: impulso (tipico per bobine) o continuo (per motori)  
3️⃣ Uscita B – Selezione modalità: uscita singola / doppia  
4️⃣ Uscita B – Modalità impulso: impulso o continuo  
5️⃣ Interruttore di collegamento – Collega l'uscita B all'uscita A (modalità slave). Attivo solo se A è impostata in modalità doppia



---

## ⚙️ Logica di Funzionamento

### 🅰️ Uscita A (Principale)
- Funziona come uscita singola o doppia
- In modalità doppia, un indirizzo DCC controlla entrambe le uscite, sia con impulso che in modo stabile
- In modalità singola, ogni uscita utilizza il proprio indirizzo

### 🅱️ Uscita B (Secondaria)
- Può funzionare in modo indipendente come A, oppure come slave di A
- In modalità collegata, B può gestire automaticamente la polarizzazione del frog; commuta i relè e il motore di scambio in una sequenza specifica per evitare cortocircuiti:
    1. Disattiva il frog
    2. Commuta lo scambio
    3. Riattiva il frog con polarità inversa

Questa temporizzazione supporta impianti con Electrofrog e Unifrog

---

## 🔗 Estensioni Modalità Slave

### Modalità segnale

Quando il collegamento tra le uscite è abilitato, l'uscita B cambia comportamento in funzione della modalità di A:
- Se A è in modalità Singola + Impulso, il decoder accetta comandi DCC EXT per segnali a 4 luci  
- Entrambe le uscite agiscono insieme come un mini-controllore di segnali  
- Il Duplex non dispone di impostazioni fisse, aspetti o preset per i segnali. Si utilizzano invece i comandi DCC EXT con cui è possibile trasmettere un valore da 0 a 255 al decoder.

Il valore funziona in binario. 255 ha un valore binario di `1111 1111`. Il nibble alto (primi 4 bit) indica quali LED devono lampeggiare; il nibble basso (ultimi 4 bit) indica quali luci devono essere accese o spente. Quando una luce è impostata per lampeggiare tramite il nibble alto, il bit corrispondente nel nibble basso deve essere `0`. **Ad esempio, se solo le prime due luci devono lampeggiare, la terza luce è spenta e la quarta è accesa: il valore è `1100 0001` = 193 decimale.**



Il software utilizzato per il plastico ferroviario deve collegare gli aspetti del segnale ai valori DCC EXT. Annotare il valore binario per ciascun aspetto desiderato e calcolare l'equivalente decimale. L'applicazione Calcolatrice integrata in Windows può essere utile — prima impostare la modalità **Programmatore**.



Come esempio prendiamo un segnale olandese di linea principale. Colleghiamo il verde ad A1, il giallo ad A2, il rosso a B1 e il riquadro del numero a B2. Il viola è il filo comune +.



Questo segnale utilizza i seguenti aspetti.

| Aspetto | Luci (V/G/R/B) | Nibble alto (bit lampeggio) | Nibble basso (bit acceso/spento) | Decimale |
|---|---|---|---|---|
| Stop | R | 0000 | 0100 | 4 |
| Via libera | G | 0000 | 0001 | 1 |
| Attenzione / Aspettarsi stop | G (giallo) | 0000 | 0010 | 2 |
| Avanzare a vista (G giallo lampeggiante) | G giallo (lamp.) | 0010 | 0000 | 32 |
| Deviata / percorso a velocità ridotta (V lampeggiante) | V (lamp.) | 0001 | 0000 | 16 |
| Velocità indicata a questo segnale (V lamp. + B acceso) | V (lamp.) + B acceso | 0001 | 1000 | 24 |
| Avvicinarsi con velocità al segnale successivo (G giallo + B acceso) | G giallo + B acceso | 0000 | 1010 | 10 |

---

## 💡 Note Tecniche

- Compatibile con l'indirizzamento DCC Roco, NMRA ed esteso
- Ogni uscita può pilotare in sicurezza bobine di scambio standard o piccoli motori
- La EEPROM memorizza l'ultima configurazione e gli indirizzi
- Il firmware supporta l'acquisizione dell'indirizzo tramite comando DCC o pressione di un pulsante (se implementato)

---

## 🧰 Sicurezza e Raccomandazioni

- Verificare sempre la corretta polarità dell'alimentazione prima di accendere
- Non superare 18 V DC
- Mantenere una distanza adeguata se si azionano contemporaneamente quattro relè ad alta corrente
- Usare un'alimentatore DC adeguato con capacità di corrente corrispondente al tipo di scambio

---

## Appendice A — Combinazioni DIP switch

### Uscite individuali        

| DIP switch | Descrizione |
|---|---|
| 00000 | A = Doppio Impulso, B = Doppio Impulso |
| 00010 | A = Doppio Impulso, B = Doppio Stabile |
| 00110 | A = Doppio Impulso, B = Singolo Stabile |
| 01000 | A = Doppio Stabile, B = Doppio Impulso |
| 01010 | A = Doppio Stabile, B = Doppio Stabile |
| 01110 | A = Doppio Stabile, B = Singolo Stabile |
| 11000 | A = Singolo Stabile, B = Doppio Impulso |
| 11010 | A = Singolo Stabile, B = Doppio Stabile |
| 11110 | A = Singolo Stabile, B = Singolo Stabile |

### Uscita B collegata all'uscita A

| DIP switch | Descrizione |
|---|---|
| 00001 | A = Doppio Impulso, B = Relè Doppio |
| 00101 | A = Doppio Impulso, B = Relè Singolo |
| 01001 | A = Doppio Stabile, B = Relè Doppio |
| 01101 | A = Doppio Stabile, B = Relè Singolo |
| 10001 | Modalità segnale |

---

📘 *Fine del Manuale*

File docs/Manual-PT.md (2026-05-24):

> 🌐 &nbsp; [🇬🇧 EN](Manual-EN.md) &nbsp;|&nbsp; [🇩🇪 DE](Manual-DE.md) &nbsp;|&nbsp; [🇫🇷 FR](Manual-FR.md) &nbsp;|&nbsp; [🇳🇱 NL](Manual-NL.md) &nbsp;|&nbsp; [🇪🇸 ES](Manual-ES.md) &nbsp;|&nbsp; [🇮🇹 IT](Manual-IT.md) &nbsp;|&nbsp; [🇵🇱 PL](Manual-PL.md) &nbsp;|&nbsp; [🇨🇿 CS](Manual-CS.md) &nbsp;|&nbsp; [🇩🇰 DA](Manual-DA.md) &nbsp;|&nbsp; [🇳🇴 NO](Manual-NO.md) &nbsp;|&nbsp; [🇸🇪 SV](Manual-SV.md) &nbsp;|&nbsp; [🇭🇺 HU](Manual-HU.md) &nbsp;|&nbsp; 🇵🇹 PT

# ⚙️ Manual do Decoder OS-Duplex

**Decoder DCC duplo para solenóides, relés e motores de agulha**



---

## 🔧 Introdução

O OS-Duplex é um decoder de acessórios DCC duplo concebido para todos os tipos de accionamento de agulhas — desde solenóides tradicionais a accionamentos por motor e módulos de relé para polarização de frog.  
Cada lado (A e B) pode funcionar de forma independente ou estar ligado ao outro.

Cada lado pode actuar como:
- 🅰️ / 🅱️ duas saídas simples independentes (cada uma com o seu próprio endereço DCC), ou
- ⚙️ uma saída dupla combinada para uma agulha de bobine dupla ou accionamento por motor.

Os sockets de relé opcionais permitem adicionar a polarização de frog ou utilizar as mesmas saídas para accionar bobines ou motores adicionais.

---

## ⚡ Alimentação

O OS-Duplex requer uma fonte de alimentação DC externa entre 12 V e 18 V DC.  
⚠️ A polaridade é absoluta. Respeite sempre as ligações correctas de "+" e "–".

- Utilize tensões mais baixas (12 V) para accionamentos por motor de agulha  
- Utilize tensões mais elevadas (até 18 V) para accionamentos por bobine

---

## 🧩 Ligações

- 🔌 DCC IN – Entrada do sinal de comando DCC  
- ⚡ POW + / POW - – Entradas de alimentação para cada secção de saída  
- ⚙️ OUT A / OUT B – Saídas de accionamento para bobines, motores ou relés  
- 🔌 Conectores de passagem – É possível ligar mais decoders Duplex nos sockets seguintes  
- Podem ser ligados até quatro módulos de relé



*Figura 1: Terminais de alimentação principal*



*Figura 2: 2 decoders Duplex ligados em cadeia*



*Figura 3: 2 módulos de relé duplo ligados*



*Figura 4: Exemplo 1 — Accionamento de bobine dupla e módulo de relé duplo*



*Figura 5: Exemplo com 2× MTB MP-1*

---

## 🎚️ Configuração por DIP-Switch

Cinco DIP switches definem todos os modos de funcionamento:

1️⃣ Saída A – Selecção de modo: saída Simples / Dupla  
2️⃣ Saída A – Modo de impulso: Impulso (bobine típica) ou Contínuo (motor)  
3️⃣ Saída B – Selecção de modo: saída Simples / Dupla  
4️⃣ Saída B – Modo de impulso: Impulso ou Contínuo  
5️⃣ Interruptor de ligação – Liga a Saída B à Saída A (modo escravo). Apenas activo se A estiver configurado em modo Duplo



---

## ⚙️ Lógica de Funcionamento

### 🅰️ Saída A (Primária)
- Funciona como saída simples ou dupla
- Em modo duplo, um endereço DCC controla ambas as saídas, quer sejam pulsadas ou contínuas
- Em modo simples, cada saída utiliza o seu próprio endereço

### 🅱️ Saída B (Secundária)
- Pode funcionar de forma independente como A ou como escravo de A
- Em funcionamento ligado, B pode tratar automaticamente a polarização de frog; comuta os relés e o motor de agulha numa sequência específica para evitar curto-circuitos:
    1. Desactivar o frog
    2. Comutar a agulha
    3. Reactivar o frog com polaridade inversa

Esta temporização suporta maquetes com agulhas Electrofrog e Uni-frog

---

## 🔗 Extensões do Modo Escravo

### Modo de sinal

Quando a ligação entre as saídas está activa, a Saída B altera o seu comportamento consoante o modo de A:
- Se A estiver em modo Simples + Impulso, o decoder aceita comandos DCC EXT para sinais de 4 lâmpadas  
- Ambas as saídas funcionam em conjunto como um controlador de sinal em miniatura  
- O Duplex não tem conceito de configurações fixas, aspectos ou predefinições para sinais. Em vez disso, utilizam-se os comandos DCC EXT com os quais é possível transmitir um valor de 0–255 ao decoder.

O valor funciona em binário. 255 tem o valor binário `1111 1111`. O nibble alto (primeiros 4 bits) indica quais os LED que devem piscar; o nibble baixo (últimos 4 bits) indica quais as luzes que devem estar acesas ou apagadas. Quando uma luz está configurada para piscar pelo nibble alto, o bit correspondente no nibble baixo tem de ser `0`. **Por exemplo, quando apenas as duas primeiras luzes devem piscar, a terceira está apagada e a quarta está acesa: o valor é `1100 0001` = 193 em decimal.**



O software que utiliza para a sua maquete ferroviária precisa de associar os aspectos do sinal aos valores DCC EXT. Anote o valor binário para cada aspecto desejado e calcule depois o equivalente decimal. A Calculadora incorporada no Windows pode ajudar — mude-a para o modo **Programador**.



Como exemplo, tomamos um sinal de linha principal neerlandês. Ligamos o verde a A1, o amarelo a A2, o vermelho a B1 e o quadro numérico a B2. O roxo é o fio comum +

texto alternativo

Este sinal utiliza os seguintes aspectos.

| Aspecto | Lâmpadas (V/Am/V/B) | Nibble alto (bits de piscar) | Nibble baixo (bits aceso/apagado) | Decimal |
|---|---|---|---|---|
| Parar | V (vermelho) | 0000 | 0100 | 4 |
| Avançar | V (verde) | 0000 | 0001 | 1 |
| Precaução / Esperar paragem | Am (amarelo) | 0000 | 0010 | 2 |
| Avançar com cautela (Am a piscar) | Am (piscar) | 0010 | 0000 | 32 |
| Divergente / via de velocidade (V a piscar) | V verde (piscar) | 0001 | 0000 | 16 |
| Velocidade indicada neste sinal (V a piscar + B aceso) | V verde (piscar) + B aceso | 0001 | 1000 | 24 |
| Aproximar com velocidade no próximo sinal (Am + B aceso) | Am aceso + B aceso | 0000 | 1010 | 10 |

---

## 💡 Notas Técnicas

- Compatível com endereçamento DCC da Roco, NMRA e estendido
- Cada saída pode accionar com segurança bobines de agulha normais ou pequenos motores
- A EEPROM guarda a última configuração e os endereços
- O firmware suporta aprendizagem de endereço por comando DCC ou por botão (se implementado)

---

## 🧰 Segurança e Recomendações

- Verifique sempre a polaridade correcta da alimentação antes de ligar
- Não exceda 18 V DC
- Mantenha espaçamento adequado ao accionar quatro relés de alta corrente simultaneamente
- Utilize uma fonte DC adequada com capacidade de corrente correspondente ao tipo de agulha

---

## Apêndice A — Combinações de DIP switch

### Saídas individuais

| DIP switches | Descrição |
|---|---|
| 00000 | A = Impulso Duplo, B = Impulso Duplo |
| 00010 | A = Impulso Duplo, B = Contínuo Duplo |
| 00110 | A = Impulso Duplo, B = Contínuo Simples |
| 01000 | A = Contínuo Duplo, B = Impulso Duplo |
| 01010 | A = Contínuo Duplo, B = Contínuo Duplo |
| 01110 | A = Contínuo Duplo, B = Contínuo Simples |
| 11000 | A = Contínuo Simples, B = Impulso Duplo |
| 11010 | A = Contínuo Simples, B = Contínuo Duplo |
| 11110 | A = Contínuo Simples, B = Contínuo Simples |

### Saída B ligada à saída A

| DIP switches | Descrição |
|---|---|
| 00001 | A = Impulso Duplo, B = Relé Duplo |
| 00101 | A = Impulso Duplo, B = Relé Simples |
| 01001 | A = Contínuo Duplo, B = Relé Duplo |
| 01101 | A = Contínuo Duplo, B = Relé Simples |
| 10001 | Modo de sinal |

---

📘 *Fim do Manual*

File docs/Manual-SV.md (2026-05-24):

> 🌐 &nbsp; [🇬🇧 EN](Manual-EN.md) &nbsp;|&nbsp; [🇩🇪 DE](Manual-DE.md) &nbsp;|&nbsp; [🇫🇷 FR](Manual-FR.md) &nbsp;|&nbsp; [🇳🇱 NL](Manual-NL.md) &nbsp;|&nbsp; [🇪🇸 ES](Manual-ES.md) &nbsp;|&nbsp; [🇮🇹 IT](Manual-IT.md) &nbsp;|&nbsp; [🇵🇱 PL](Manual-PL.md) &nbsp;|&nbsp; [🇨🇿 CS](Manual-CS.md) &nbsp;|&nbsp; [🇩🇰 DA](Manual-DA.md) &nbsp;|&nbsp; [🇳🇴 NO](Manual-NO.md) &nbsp;|&nbsp; 🇸🇪 SV &nbsp;|&nbsp; [🇭🇺 HU](Manual-HU.md) &nbsp;|&nbsp; [🇵🇹 PT](Manual-PT.md)

# ⚙️ OS-Duplex Decoder-manual

**Dubbel DCC-decoder för solenoider, reläer och växelmotorer**



---

## 🔧 Introduktion

OS-Duplex är en dubbel DCC-tillbehörsdecoder utformad för alla typer av växelmotorer — från traditionella solenoider till motordrivna enheter och relämoduler för hjärtpunktspolarisering.  
Varje sida (A och B) kan arbeta oberoende eller länkas samman.

Varje sida kan fungera antingen som:
- 🅰️ / 🅱️ två oberoende enkelutgångar (varje med sin egen DCC-adress), eller
- ⚙️ en kombinerad dubbelutgång för en tvillingspole- eller motordrivet växeldon.

Optionella reläsocketar låter dig lägga till hjärtpunktspolarisering, eller använda samma utgångar för att driva extra spoler eller motorer.

---

## ⚡ Strömförsörjning

OS-Duplex kräver en extern DC-strömförsörjning mellan 12 V och 18 V DC.  
⚠️ Polariteten är absolut. Observera alltid korrekt "+" och "–"-anslutningar.

- Använd lägre spänningar (12 V) för växelmotordrivningar  
- Använd högre spänningar (upp till 18 V) för spoledrivningar

---

## 🧩 Anslutningar

- 🔌 DCC IN – Ingång för DCC-kommandosignalen  
- ⚡ POW + / POW - – Strömingångar för varje utgångsdel  
- ⚙️ OUT A / OUT B – Drivutgångar för spoler, motorer eller reläer  
- 🔌 Genomkopplingskontakter – Du kan koppla in fler Duplex-decoders i de efterföljande socketnarna  
- Du kan koppla in upp till fyra relämoduler



*Figur 1: Huvudströmplintarna*



*Figur 2: 2 Duplex-decoders kopplade i serie*



*Figur 3: 2 dubbla relämoduler inkopplade*



*Figur 4: Exempel 1 – dubbelspoldrivning och dubbel relämodul*



*Figur 5: Exempel med 2× MTB MP-1*

---

## 🎚️ DIP-switch-konfiguration

Fem DIP-switchar definierar alla driftlägen:

1️⃣ Utgång A – Lägesval: Enkel / Dubbel utgång  
2️⃣ Utgång A – Pulsläge: Puls (typisk spole) eller Kontinuerlig (motor)  
3️⃣ Utgång B – Lägesval: Enkel / Dubbel utgång  
4️⃣ Utgång B – Pulsläge: Puls eller Kontinuerlig  
5️⃣ Länkbrytare – Länkar utgång B till utgång A (slavläge). Aktiv endast om A är inställd på dubbelläge



---

## ⚙️ Driftlogik

### 🅰️ Utgång A (Primär)
- Fungerar som enkel eller dubbel utgång
- I dubbelläge styr en DCC-adress båda utgångarna, oavsett om de är pulsade eller kontinuerliga
- I enkelläge använder varje utgång sin egen adress

### 🅱️ Utgång B (Sekundär)
- Kan köras oberoende som A eller som slav till A
- I länkat läge kan B automatiskt hantera hjärtpunktspolarisering; den växlar reläerna och växelmotorn i en bestämd sekvens för att förhindra kortslutningar:
    1. Spänningslös hjärtpunkt
    2. Växel om
    3. Åter spänning på hjärtpunkt med omvänd polaritet

Denna tidsinställning stöder Electrofrog- och Uni-frog-banor

---

## 🔗 Slavlägesutvidgningar

### Signalläge

När länken är aktiverad mellan utgångarna ändrar utgång B beteende beroende på A:s läge:
- Om A är Enkel + Puls accepterar decodern DCC EXT-kommandon för 4-lampssignaler  
- Båda utgångarna fungerar tillsammans som en miniatyr signalstyrare  
- OS-Duplex har inget koncept för fasta inställningar, aspekter eller förinställningar när det gäller signaler. Istället använder vi DCC EXT-kommandon med vilka vi kan skicka ett värde på 0–255 till decodern.

Värdet fungerar i binärt. 255 har det binära värdet `1111 1111`. Den höga nibblén (de första 4 bitarna) anger vilka LED:ar som ska blinka; den låga nibblén (de sista 4 bitarna) anger vilka lampor som ska vara på eller av. När en lampa är inställd att blinka via den höga nibblén måste motsvarande bit i den låga nibblén vara `0`. **Till exempel, när bara de första två lamporna ska blinka, den tredje lampan är av och den fjärde lampan är på: värdet är `1100 0001` = 193 decimalt.**



Den programvara du använder för din modellbana måste koppla signalaspekterna till DCC EXT-värden. Skriv ned det binära värdet för varje önskad aspekt och beräkna sedan decimalekvivalenten. Windows inbyggda kalkylatorapp kan hjälpa till — växla den till **Programmerare**-läge först.



Som exempel tar vi en holländsk huvudlinjessignal. Vi ansluter grönt till A1, gult till A2, rött till B1 och nummerrutan till B2. Lila är den gemensamma +-ledaren.

alternativ text

Den här signalen använder dessa aspekter.

| Aspekt | Lampor (G/Y/R/W) | Hög nibble (blinkbitar) | Låg nibble (på/av-bitar) | Decimalt |
|---|---|---|---|---|
| Stopp | R | 0000 | 0100 | 4 |
| Kör | G | 0000 | 0001 | 1 |
| Varning / Förvänta stopp | Y | 0000 | 0010 | 2 |
| Kör med sikt (Y blinkar) | Y (blinkar) | 0010 | 0000 | 32 |
| Avvikande / hastighetsspår (G blinkar) | G (blinkar) | 0001 | 0000 | 16 |
| Hastighet angiven vid denna signal (G blinkar + W på) | G (blinkar) + W på | 0001 | 1000 | 24 |
| Närmande med hastighet vid nästa signal (Y + W på) | Y på + W på | 0000 | 1010 | 10 |

---

## 💡 Tekniska noteringar

- Kompatibel med Roco, NMRA och utökad DCC-adressering
- Varje utgång kan säkert driva standardväxelspoler eller små motorer
- EEPROM lagrar senaste konfiguration och adresser
- Firmware stöder adressinlärning via DCC-kommando eller knapptryckning (om implementerat)

---

## 🧰 Säkerhet och rekommendationer

- Kontrollera alltid korrekt matningspolaritet innan du slår på strömmen
- Överskrid inte 18 V DC
- Håll tillräckligt avstånd vid körning av fyra högströmreläer samtidigt
- Använd en lämplig DC-källa med strömkapacitet som matchar din växeltyp

---

## Bilaga A – DIP-switch-kombinationer

### Individuella utgångar

| DIP-switchar | Beskrivning |
|---|---|
| 00000 | A = Dubbel puls, B = Dubbel puls |
| 00010 | A = Dubbel puls, B = Dubbel kontinuerlig |
| 00110 | A = Dubbel puls, B = Enkel kontinuerlig |
| 01000 | A = Dubbel kontinuerlig, B = Dubbel puls |
| 01010 | A = Dubbel kontinuerlig, B = Dubbel kontinuerlig |
| 01110 | A = Dubbel kontinuerlig, B = Enkel kontinuerlig |
| 11000 | A = Enkel kontinuerlig, B = Dubbel puls |
| 11010 | A = Enkel kontinuerlig, B = Dubbel kontinuerlig |
| 11110 | A = Enkel kontinuerlig, B = Enkel kontinuerlig |

### Utgång B länkad till utgång A

| DIP-switchar | Beskrivning |
|---|---|
| 00001 | A = Dubbel puls, B = Dubbelt relä |
| 00101 | A = Dubbel puls, B = Enkelt relä |
| 01001 | A = Dubbel kontinuerlig, B = Dubbelt relä |
| 01101 | A = Dubbel kontinuerlig, B = Enkelt relä |
| 10001 | Signalläge |

---

📘 *Slut på manualen*

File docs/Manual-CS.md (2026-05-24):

> 🌐 &nbsp; [🇬🇧 EN](Manual-EN.md) &nbsp;|&nbsp; [🇩🇪 DE](Manual-DE.md) &nbsp;|&nbsp; [🇫🇷 FR](Manual-FR.md) &nbsp;|&nbsp; [🇳🇱 NL](Manual-NL.md) &nbsp;|&nbsp; [🇪🇸 ES](Manual-ES.md) &nbsp;|&nbsp; [🇮🇹 IT](Manual-IT.md) &nbsp;|&nbsp; [🇵🇱 PL](Manual-PL.md) &nbsp;|&nbsp; 🇨🇿 CS &nbsp;|&nbsp; [🇩🇰 DA](Manual-DA.md) &nbsp;|&nbsp; [🇳🇴 NO](Manual-NO.md) &nbsp;|&nbsp; [🇸🇪 SV](Manual-SV.md) &nbsp;|&nbsp; [🇭🇺 HU](Manual-HU.md) &nbsp;|&nbsp; [🇵🇹 PT](Manual-PT.md)

# ⚙️ Manuál dekodéru OS-Duplex

**Dvojitý DCC dekodér pro solenoidy, relé a pohony výhybek**



---

## 🔧 Úvod

OS-Duplex je dvojitý DCC příslušenský dekodér navržený pro všechny typy pohonů výhybek — od tradičních solenoidů po motorické pohony a relé moduly pro polarizaci srdcovky.  
Každá strana (A a B) může pracovat samostatně nebo být propojena dohromady.

Každá strana může fungovat jako:
- 🅰️ / 🅱️ dva nezávislé samostatné výstupy (každý s vlastní DCC adresou), nebo
- ⚙️ jeden kombinovaný dvojitý výstup pro výhybku s dvousmyčkovým nebo motorickým pohonem.

Volitelné zásuvky pro relé umožňují přidání polarizace srdcovky nebo použití stejných výstupů pro pohon dalších cívek či motorů.

---

## ⚡ Napájení

OS-Duplex vyžaduje externí DC napájení mezi 12 V a 18 V DC.  
⚠️ Polarita je absolutní. Vždy dodržujte správné zapojení „+" a „–".

- Používejte nižší napětí (12 V) pro motorické pohony výhybek  
- Používejte vyšší napětí (až 18 V) pro pohony cívek

---

## 🧩 Připojení

- 🔌 DCC IN – vstup pro DCC řídicí signál  
- ⚡ POW + / POW - – napájecí vstupy pro každou výstupní sekci  
- ⚙️ OUT A / OUT B – pohonné výstupy pro cívky, motory nebo relé  
- 🔌 Průchozí konektory – do následujících zásuvek lze zapojit další Duplex dekodéry  
- Lze zapojit až čtyři relé moduly



*Obrázek 1: Hlavní napájecí svorky*



*Obrázek 2: 2 dekodéry Duplex zapojené do řetězu*



*Obrázek 3: 2 dvojité relé moduly zapojené*



*Obrázek 4: Příklad 1 – dvojitý pohon cívky a dvojitý relé modul*



*Obrázek 5: Příklad s 2× MTB MP-1*

---

## 🎚️ Konfigurace DIP přepínačů

Pět DIP přepínačů definuje všechny provozní režimy:

1️⃣ Výstup A – výběr režimu: Samostatný / Dvojitý výstup  
2️⃣ Výstup A – režim impulzu: Impulz (typická cívka) nebo Trvalý (motor)  
3️⃣ Výstup B – výběr režimu: Samostatný / Dvojitý výstup  
4️⃣ Výstup B – režim impulzu: Impulz nebo Trvalý  
5️⃣ Propojovací přepínač – propojí výstup B s výstupem A (podřízený režim). Aktivní pouze pokud je A nastaven na dvojitý režim



---

## ⚙️ Logika fungování

### 🅰️ Výstup A (primární)
- Pracuje jako samostatný nebo dvojitý výstup
- V dvojitém režimu jedna DCC adresa ovládá oba výstupy, ať jsou v impulzním nebo trvalém režimu
- V samostatném režimu každý výstup používá vlastní adresu

### 🅱️ Výstup B (sekundární)
- Může fungovat nezávisle jako A nebo jako podřízený k A
- V propojeném provozu může B automaticky zajišťovat polarizaci srdcovky; přepíná relé a pohon výhybky v konkrétní sekvenci, aby nedocházelo ke zkratům:
    1. Odpojit srdcovku od napájení
    2. Přehodit výhybku
    3. Znovu připojit srdcovku s opačnou polaritou

Toto časování podporuje kolejnice Electrofrog a Uni-frog

---

## 🔗 Rozšíření podřízeného režimu

### Režim návěstidla

Pokud je aktivováno propojení výstupů, výstup B mění chování v závislosti na režimu A:
- Pokud je A Samostatný + Impulz, dekodér přijímá DCC Extended příkazy pro 4-lampová návěstidla  
- Oba výstupy společně fungují jako miniaturní ovladač návěstidel  
- OS-Duplex nemá žádný koncept pevných nastavení, aspektů ani předvoleb pro návěstidla. Místo toho používáme DCC Extended příkazy, pomocí nichž lze do dekodéru přenést hodnotu 0–255.

Hodnota funguje binárně. 255 má binární hodnotu `1111 1111`. Horní nibble (první 4 bity) říká, které LED by měly blikat; dolní nibble (poslední 4 bity) říká, která světla by měla být zapnuta nebo vypnuta. Pokud je světlo nastaveno na blikání přes horní nibble, musí být odpovídající bit v dolním nibble `0`. **Například když mají blikat pouze první dvě světla, třetí světlo je vypnuto a čtvrté světlo je zapnuto: hodnota je `1100 0001` = 193 desítkově.**



Software, který používáte pro své kolejiště, musí propojit aspekty návěstidel s hodnotami DCC Extended. Zapište binární hodnotu pro každý požadovaný aspekt a poté vypočítejte desítkový ekvivalent. Může pomoci vestavěná kalkulačka systému Windows — nejprve ji přepněte do režimu **Programátor**.



Jako příklad vezmeme holandské hlavní traťové návěstidlo. Zelené připojíme k A1, žluté k A2, červené k B1 a číselný box k B2. Fialová je společný + vodič.



Toto návěstidlo používá tyto aspekty.

| Aspekt | Lampy (G/Y/R/W) | Horní nibble (bity blikání) | Dolní nibble (bity zapnuto/vypnuto) | Desítkově |
|---|---|---|---|---|
| Stůj | R | 0000 | 0100 | 4 |
| Volná jízda | G | 0000 | 0001 | 1 |
| Opatrně / Čekej zastavení | Y | 0000 | 0010 | 2 |
| Jízda na dohled (Y bliká) | Y (blikání) | 0010 | 0000 | 32 |
| Odbočení / trasa rychlostí (G bliká) | G (blikání) | 0001 | 0000 | 16 |
| Rychlost udána na tomto návěstidle (G bliká + W SVÍTÍ) | G (blikání) + W SVÍTÍ | 0001 | 1000 | 24 |
| Přiblížení s rychlostí k dalšímu návěstidlu (Y + W SVÍTÍ) | Y SVÍTÍ + W SVÍTÍ | 0000 | 1010 | 10 |

---

## 💡 Technické poznámky

- Kompatibilní s Roco, NMRA a rozšířeným DCC adresováním
- Každý výstup bezpečně napájí standardní výhybkové cívky nebo malé motory
- EEPROM ukládá poslední konfiguraci a adresy
- Firmware podporuje učení adres prostřednictvím DCC příkazu nebo stisku tlačítka (pokud je implementováno)

---

## 🧰 Bezpečnost a doporučení

- Vždy ověřte správnou polaritu napájení před zapnutím
- Nepřekračujte 18 V DC
- Zachovejte dostatečný odstup při souběžném pohonu čtyř relé s vysokým odběrem
- Používejte vhodný DC zdroj s proudovou kapacitou odpovídající typu vaší výhybky

---

## Příloha A: kombinace DIP přepínačů

### Samostatné výstupy        

| DIP přepínače | Popis |
|---|---|
| 00000 | A = Dvojitý impulz, B = Dvojitý impulz |
| 00010 | A = Dvojitý impulz, B = Dvojitý trvalý |
| 00110 | A = Dvojitý impulz, B = Samostatný trvalý |
| 01000 | A = Dvojitý trvalý, B = Dvojitý impulz |
| 01010 | A = Dvojitý trvalý, B = Dvojitý trvalý |
| 01110 | A = Dvojitý trvalý, B = Samostatný trvalý |
| 11000 | A = Samostatný trvalý, B = Dvojitý impulz |
| 11010 | A = Samostatný trvalý, B = Dvojitý trvalý |
| 11110 | A = Samostatný trvalý, B = Samostatný trvalý |

### Výstup B propojen s výstupem A

| DIP přepínače | Popis |
|---|---|
| 00001 | A = Dvojitý impulz, B = Dvojité relé |
| 00101 | A = Dvojitý impulz, B = Samostatné relé |
| 01001 | A = Dvojitý trvalý, B = Dvojité relé |
| 01101 | A = Dvojitý trvalý, B = Samostatné relé |
| 10001 | Režim návěstidla |

---

📘 *Konec manuálu*

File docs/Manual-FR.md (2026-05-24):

> 🌐 &nbsp; [🇬🇧 EN](Manual-EN.md) &nbsp;|&nbsp; [🇩🇪 DE](Manual-DE.md) &nbsp;|&nbsp; 🇫🇷 FR &nbsp;|&nbsp; [🇳🇱 NL](Manual-NL.md) &nbsp;|&nbsp; [🇪🇸 ES](Manual-ES.md) &nbsp;|&nbsp; [🇮🇹 IT](Manual-IT.md) &nbsp;|&nbsp; [🇵🇱 PL](Manual-PL.md) &nbsp;|&nbsp; [🇨🇿 CS](Manual-CS.md) &nbsp;|&nbsp; [🇩🇰 DA](Manual-DA.md) &nbsp;|&nbsp; [🇳🇴 NO](Manual-NO.md) &nbsp;|&nbsp; [🇸🇪 SV](Manual-SV.md) &nbsp;|&nbsp; [🇭🇺 HU](Manual-HU.md) &nbsp;|&nbsp; [🇵🇹 PT](Manual-PT.md)

# ⚙️ Manuel du décodeur OS-Duplex

**Décodeur DCC double pour solénoïdes, relais et moteurs d'aiguille**



---

## 🔧 Introduction

Le OS-Duplex est un décodeur DCC accessoire double conçu pour tous types d'entraînements d'aiguille — des solénoïdes traditionnels aux entraînements moteur et modules relais pour la polarisation des cœurs d'aiguille.  
Chaque côté (A et B) peut fonctionner de manière indépendante ou être couplé ensemble.

Chaque côté peut fonctionner soit comme :
- 🅰️ / 🅱️ deux sorties individuelles indépendantes (chacune avec sa propre adresse DCC), ou
- ⚙️ une sortie double combinée pour une aiguille à double bobine ou à entraînement moteur.

Des prises relais optionnelles permettent d'ajouter la polarisation du cœur d'aiguille, ou d'utiliser les mêmes sorties pour entraîner des bobines ou moteurs supplémentaires.

---

## ⚡ Alimentation électrique

Le OS-Duplex nécessite une alimentation DC externe entre 12 V et 18 V DC.  
⚠️ La polarité est absolue. Respectez toujours les connexions « + » et « – » correctes.

- Utilisez des tensions plus basses (12 V) pour les entraînements moteur d'aiguille  
- Utilisez des tensions plus élevées (jusqu'à 18 V) pour les entraînements à bobine

---

## 🧩 Connexions

- 🔌 DCC IN – Entrée pour le signal de commande DCC  
- ⚡ POW + / POW - – Entrées d'alimentation pour chaque section de sortie  
- ⚙️ OUT A / OUT B – Sorties d'entraînement pour bobines, moteurs ou relais  
- 🔌 Connecteurs traversants – Vous pouvez brancher d'autres décodeurs Duplex dans les prises suivantes  
- Vous pouvez brancher jusqu'à quatre modules relais



*Figure 1 : Bornes d'alimentation principales*



*Figure 2 : 2 décodeurs Duplex en guirlande*



*Figure 3 : 2 modules relais doubles branchés*



*Figure 4 : Exemple 1 — entraînement à double bobine et module relais double*



*Figure 5 : Exemple avec 2x MTB MP-1*

---

## 🎚️ Configuration par commutateurs DIP

Cinq commutateurs DIP définissent tous les modes de fonctionnement :

1️⃣ Sortie A – Sélection du mode : sortie Simple / Double  
2️⃣ Sortie A – Mode impulsion : Impulsion (bobine classique) ou Continu (moteur)  
3️⃣ Sortie B – Sélection du mode : sortie Simple / Double  
4️⃣ Sortie B – Mode impulsion : Impulsion ou Continu  
5️⃣ Commutateur de liaison – Relie la sortie B à la sortie A (mode esclave). Actif uniquement si A est en mode Double



---

## ⚙️ Logique de fonctionnement

### 🅰️ Sortie A (principale)
- Fonctionne en sortie simple ou double
- En mode double, une adresse DCC contrôle les deux sorties, qu'elles soient en impulsion ou en continu
- En mode simple, chaque sortie utilise sa propre adresse

### 🅱️ Sortie B (secondaire)
- Peut fonctionner indépendamment comme A ou en mode esclave de A
- En fonctionnement couplé, B peut gérer automatiquement la polarisation du cœur ; elle commute les relais et le moteur d'aiguille dans une séquence spécifique pour éviter les courts-circuits :
    1. Désactiver le cœur
    2. Commuter l'aiguille
    3. Réactiver le cœur avec la polarité opposée

Ce séquençage prend en charge les réseaux Electrofrog et Uni-frog

---

## 🔗 Extensions en mode esclave

### Mode signal

Lorsque la liaison entre les sorties est activée, la sortie B change de comportement selon le mode de A :
- Si A est en mode Simple + Impulsion, le décodeur accepte les commandes DCC EXT pour les signaux à 4 feux  
- Les deux sorties fonctionnent ensemble comme un contrôleur de signal miniature  
- Le Duplex n'a pas de notion de réglages fixes, d'aspects ou de présélections pour les signaux. Nous utilisons à la place les commandes DCC EXT avec lesquelles nous pouvons transmettre une valeur de 0 à 255 au décodeur.

La valeur fonctionne en binaire. 255 a une valeur binaire de `1111 1111`. La partie haute (les 4 premiers bits) indique quels LED doivent clignoter ; la partie basse (les 4 derniers bits) indique quels feux doivent être allumés ou éteints. Quand un feu est réglé pour clignoter via la partie haute, le bit correspondant dans la partie basse doit être `0`. **Par exemple, quand seuls les deux premiers feux doivent clignoter, le troisième feu est éteint et le quatrième feu est allumé : la valeur est `1100 0001` = 193 en décimal.**



Le logiciel que vous utilisez pour votre réseau ferroviaire miniature doit associer les aspects de signal aux valeurs DCC EXT. Notez la valeur binaire pour chaque aspect souhaité puis calculez l'équivalent décimal. La calculatrice intégrée de Windows peut vous aider — passez-la d'abord en mode **Programmeur**.



Comme exemple, nous prenons un signal de ligne principale néerlandais. Nous connectons le vert sur A1, le jaune sur A2, le rouge sur B1 et la boîte numéro sur B2. Le violet est le fil commun +.

Texte alternatif

Ce signal utilise ces aspects.

| Aspect | Feux (V/J/R/B) | Partie haute (bits clignotement) | Partie basse (bits allumé/éteint) | Décimal |
|---|---|---|---|---|
| Arrêt | R | 0000 | 0100 | 4 |
| Voie libre | V | 0000 | 0001 | 1 |
| Prudence / Prévoir l'arrêt | J | 0000 | 0010 | 2 |
| Avancer à vue (J clignotant) | J (flash) | 0010 | 0000 | 32 |
| Déviation / voie de vitesse (V clignotant) | V (flash) | 0001 | 0000 | 16 |
| Vitesse indiquée à ce signal (V clignotant + B allumé) | V (flash) + B allumé | 0001 | 1000 | 24 |
| Approcher avec vitesse au prochain signal (J + B allumé) | J allumé + B allumé | 0000 | 1010 | 10 |

---

## 💡 Notes techniques

- Compatible avec l'adressage DCC Roco, NMRA et étendu
- Chaque sortie peut alimenter en toute sécurité des bobines d'aiguille standard ou de petits moteurs
- L'EEPROM mémorise la dernière configuration et les adresses
- Le firmware prend en charge l'apprentissage d'adresse via commande DCC ou entrée bouton (si implémenté)

---

## 🧰 Sécurité et recommandations

- Vérifiez toujours la polarité correcte de l'alimentation avant la mise sous tension
- Ne dépassez pas 18 V DC
- Maintenez un espacement suffisant si vous entraînez quatre relais à fort courant simultanément
- Utilisez une alimentation DC adaptée avec une capacité en courant correspondant à votre type d'aiguille

---

## Annexe A, combinaisons de commutateurs DIP

### Sorties individuelles        

| Commutateurs DIP | Description |
|---|---|
| 00000 | A = Double Impulsion, B = Double Impulsion |
| 00010 | A = Double Impulsion, B = Double Continu |
| 00110 | A = Double Impulsion, B = Simple Continu |
| 01000 | A = Double Continu, B = Double Impulsion |
| 01010 | A = Double Continu, B = Double Continu |
| 01110 | A = Double Continu, B = Simple Continu |
| 11000 | A = Simple Continu, B = Double Impulsion |
| 11010 | A = Simple Continu, B = Double Continu |
| 11110 | A = Simple Continu, B = Simple Continu |

### Sortie B couplée à la sortie A

| Commutateurs DIP | Description |
|---|---|
| 00001 | A = Double Impulsion, B = Double Relais |
| 00101 | A = Double Impulsion, B = Simple Relais |
| 01001 | A = Double Continu, B = Double Relais |
| 01101 | A = Double Continu, B = Simple Relais |
| 10001 | Mode signal |

---

📘 *Fin du manuel*

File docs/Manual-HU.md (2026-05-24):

> 🌐 &nbsp; [🇬🇧 EN](Manual-EN.md) &nbsp;|&nbsp; [🇩🇪 DE](Manual-DE.md) &nbsp;|&nbsp; [🇫🇷 FR](Manual-FR.md) &nbsp;|&nbsp; [🇳🇱 NL](Manual-NL.md) &nbsp;|&nbsp; [🇪🇸 ES](Manual-ES.md) &nbsp;|&nbsp; [🇮🇹 IT](Manual-IT.md) &nbsp;|&nbsp; [🇵🇱 PL](Manual-PL.md) &nbsp;|&nbsp; [🇨🇿 CS](Manual-CS.md) &nbsp;|&nbsp; [🇩🇰 DA](Manual-DA.md) &nbsp;|&nbsp; [🇳🇴 NO](Manual-NO.md) &nbsp;|&nbsp; [🇸🇪 SV](Manual-SV.md) &nbsp;|&nbsp; 🇭🇺 HU &nbsp;|&nbsp; [🇵🇹 PT](Manual-PT.md)

# ⚙️ OS-Duplex Dekóder Kézikönyv

**Kettős DCC dekóder szolonoidokhoz, relékhez és kitérőmotorokhoz**



---

## 🔧 Bevezetés

Az OS-Duplex egy kettős DCC kiegészítő dekóder, amelyet minden típusú kitérőmeghajtóhoz terveztek — a hagyományos szolonoidoktól a motoros meghajtókon át a szárpolarizáló relés modulokig.  
Mindkét oldal (A és B) önállóan működhet, vagy összekapcsolható egymással.

Mindkét oldal kétféleképpen működhet:
- 🅰️ / 🅱️ két független egyes kimenetként (mindegyik saját DCC-címmel), vagy
- ⚙️ egy kombinált dupla kimenetként ikertekercsű vagy motoros kitérőmeghajtóhoz.

Opcionális relés foglalatokkal szárpolarizálás adható hozzá, vagy ugyanezek a kimenetek plusz tekercsek vagy motorok meghajtására is használhatók.

---

## ⚡ Tápellátás

Az OS-Duplex 12 V és 18 V DC közötti külső egyenfeszültségű tápot igényel.  
⚠️ A polaritás abszolút. Mindig tartsd be a helyes „+" és „–" csatlakoztatást.

- Alacsonyabb feszültséget (12 V) használj kitérőmotor-meghajtókhoz  
- Magasabb feszültséget (legfeljebb 18 V) tekercs-meghajtókhoz

---

## 🧩 Csatlakozások

- 🔌 DCC IN – A DCC parancsjelek bemenete  
- ⚡ POW + / POW - – Tápbemenetek mindkét kimeneti szakaszhoz  
- ⚙️ OUT A / OUT B – Meghajtó kimenetek tekercsekhez, motorokhoz vagy relékhez  
- 🔌 Átmenő csatlakozók – A következő foglalatokba további Duplex dekódereket csatlakoztathatsz  
- Legfeljebb négy relés modul csatlakoztatható



*1. ábra: Fő tápcsatlakozók*



*2. ábra: 2 Duplex dekóder láncolva*



*3. ábra: 2 dupla relés modul bedugva*



*4. ábra: 1. példa — Dupla tekercs-meghajtó és dupla relés modul*



*5. ábra: Példa 2x MTB MP-1 alkalmazással*

---

## 🎚️ DIP-Kapcsoló Konfiguráció

Öt DIP-kapcsoló határozza meg az összes üzemmódot:

1️⃣ A kimenet – Módválasztás: Egyes / Dupla kimenet  
2️⃣ A kimenet – Impulzusmód: Impulzus (tipikus tekercs) vagy Folyamatos (motor)  
3️⃣ B kimenet – Módválasztás: Egyes / Dupla kimenet  
4️⃣ B kimenet – Impulzusmód: Impulzus vagy Folyamatos  
5️⃣ Összekapcsoló kapcsoló – B kimenetet A kimenethez köti (slave mód). Csak akkor aktív, ha A dupla módra van állítva



---

## ⚙️ Működési Logika

### 🅰️ A Kimenet (Elsődleges)
- Egyes vagy dupla kimenetként működik
- Dupla módban egyetlen DCC-cím vezérli mindkét kimenetet, akár impulzusos, akár folyamatos üzemben
- Egyes módban minden kimenet saját címet használ

### 🅱️ B Kimenet (Másodlagos)
- Futhat önállóan, mint A, vagy A melletti slave-ként
- Összekapcsolt üzemben B automatikusan kezelheti a szárpolarizálást; a reléket és a kitérőmotort meghatározott sorrendben kapcsolja, hogy megakadályozza a rövidzárlatokat:
    1. Szár feszültségtelenítése
    2. Kitérő kapcsolása
    3. Szár újra feszültség alá helyezése ellentétes polaritással

Ez az időzítés támogatja az Electrofrog és Uni-frog pályákat

---

## 🔗 Slave Módú Bővítések

### Jelzőmód

Amikor a kimenetek közötti összekötés engedélyezve van, a B kimenet viselkedése az A mód függvényében változik:
- Ha A Egyes + Impulzus módban van, a dekóder DCC Extended parancsokat fogad el 4 lámpás jelzőkhöz  
- Mindkét kimenet együtt működik mint egy miniatűr jelzővezérlő  
- A Duplex nem rendelkezik rögzített beállításokkal, aspektusokkal vagy előbeállításokkal a jelzők tekintetében. Ehelyett DCC Extended parancsokat használunk, amelyekkel 0–255 értéket küldhetünk a dekódernek.

Az érték bináris alapon működik. A 255 bináris értéke `1111 1111`. A felső nibble (első 4 bit) azt mondja meg, melyik LED-ek villogjanak; az alsó nibble (utolsó 4 bit) azt, melyik fények legyenek be- vagy kikapcsolva. Ha egy fényt villogásra állítunk a felső nibble-ben, az alsó nibble megfelelő bitje `0` kell legyen. **Például, ha csak az első két fény villogjon, a harmadik ki van kapcsolva, és a negyedik be van kapcsolva: az érték `1100 0001` = 193 decimálisan.**



A modellvasút-pályához használt szoftvernek az jelzőaspektusokat DCC Extended értékekhez kell rendelnie. Írd le az egyes kívánt aspektusok bináris értékét, majd számítsd ki a decimális megfelelőjét. A Windows beépített Számológép alkalmazása segíthet — előbb kapcsold **Programozó** módra.



Példaként egy holland fővonalas jelzőt veszünk. A zöldet az A1-hez, a sárgát az A2-höz, a pirosat a B1-hez, a számdobozt a B2-höz csatlakoztatjuk. A lila a közös + vezéték.



Ez a jelző az alábbi aspektusokat használja.

| Aspektus | Lámpák (Z/S/P/F) | Felső nibble (villogás bitek) | Alsó nibble (be/ki bitek) | Decimális |
|---|---|---|---|---|
| Megállj | P | 0000 | 0100 | 4 |
| Haladj | Z | 0000 | 0001 | 1 |
| Figyelem / Megállásra számíts | S | 0000 | 0010 | 2 |
| Látótávolságra haladj (S villog) | S (villog) | 0010 | 0000 | 32 |
| Kitérő / sebesség útvonal (Z villog) | Z (villog) | 0001 | 0000 | 16 |
| Sebesség jelezve ennél a jelzőnél (Z villog + F BE) | Z (villog) + F BE | 0001 | 1000 | 24 |
| Közelíts sebességgel a következő jelzőhöz (S + F BE) | S BE + F BE | 0000 | 1010 | 10 |

---

## 💡 Műszaki Megjegyzések

- Kompatibilis Roco, NMRA és kiterjesztett DCC-címzéssel
- Minden kimenet biztonságosan meghajtja a szabványos kitérőtekercseket vagy kis motorokat
- Az EEPROM tárolja az utolsó konfigurációt és a címeket
- A firmware DCC-paranccsal vagy gombnyomással való cím-tanulást is támogat (ha megvalósítva)

---

## 🧰 Biztonsági Irányelvek

- Bekapcsolás előtt mindig ellenőrizd a helyes tápellátás-polaritást
- Ne haladj meg 18 V DC-t
- Tartsd be a megfelelő távolságot, ha egyszerre négy nagy áramú relét hajtasz meg
- Megfelelő DC tápot használj, amelynek áramerőssége megfelel a kitérő típusának

---

## A. Függelék: DIP-kapcsoló kombinációk

### Független kimenetek        

| DIP-kapcsolók | Leírás |
|---|---|
| 00000 | A = Dupla Impulzus, B = Dupla Impulzus |
| 00010 | A = Dupla Impulzus, B = Dupla Folyamatos |
| 00110 | A = Dupla Impulzus, B = Egyes Folyamatos |
| 01000 | A = Dupla Folyamatos, B = Dupla Impulzus |
| 01010 | A = Dupla Folyamatos, B = Dupla Folyamatos |
| 01110 | A = Dupla Folyamatos, B = Egyes Folyamatos |
| 11000 | A = Egyes Folyamatos, B = Dupla Impulzus |
| 11010 | A = Egyes Folyamatos, B = Dupla Folyamatos |
| 11110 | A = Egyes Folyamatos, B = Egyes Folyamatos |

### B kimenet az A kimenethez kötve

| DIP-kapcsolók | Leírás |
|---|---|
| 00001 | A = Dupla Impulzus, B = Dupla Relé |
| 00101 | A = Dupla Impulzus, B = Egyes Relé |
| 01001 | A = Dupla Folyamatos, B = Dupla Relé |
| 01101 | A = Dupla Folyamatos, B = Egyes Relé |
| 10001 | Jelzőmód |

---

📘 *Kézikönyv vége*

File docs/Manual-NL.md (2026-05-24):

> 🌐 &nbsp; [🇬🇧 EN](Manual-EN.md) &nbsp;|&nbsp; [🇩🇪 DE](Manual-DE.md) &nbsp;|&nbsp; [🇫🇷 FR](Manual-FR.md) &nbsp;|&nbsp; 🇳🇱 NL &nbsp;|&nbsp; [🇪🇸 ES](Manual-ES.md) &nbsp;|&nbsp; [🇮🇹 IT](Manual-IT.md) &nbsp;|&nbsp; [🇵🇱 PL](Manual-PL.md) &nbsp;|&nbsp; [🇨🇿 CS](Manual-CS.md) &nbsp;|&nbsp; [🇩🇰 DA](Manual-DA.md) &nbsp;|&nbsp; [🇳🇴 NO](Manual-NO.md) &nbsp;|&nbsp; [🇸🇪 SV](Manual-SV.md) &nbsp;|&nbsp; [🇭🇺 HU](Manual-HU.md) &nbsp;|&nbsp; [🇵🇹 PT](Manual-PT.md)

# ⚙️ OS-Duplex Decoder Handleiding

**Dubbele DCC-decoder voor magneten, relais en wisselaandrijvingen**



---

## 🔧 Inleiding

De OS-Duplex is een dubbele DCC-accessoire­decoder ontworpen voor alle soorten wisselaandrijvingen — van traditionele magneten tot motoraandrijvingen en relais­modules voor hartpunt­polarisering.  
Elke kant (A en B) kan onafhankelijk werken of aan elkaar worden gekoppeld.

Elke kant kan fungeren als:
- 🅰️ / 🅱️ twee onafhankelijke enkele uitgangen (elk met een eigen DCC-adres), of
- ⚙️ één gecombineerde dubbele uitgang voor een twee­spoels- of motoraandrijving.

Optionele relais­sockets maken het mogelijk hartpunt­polarisering toe te voegen, of dezelfde uitgangen te gebruiken voor extra spoelen of motoren.

---

## ⚡ Voeding

De OS-Duplex vereist een externe DC-voeding tussen 12 V en 18 V DC.  
⚠️ De polariteit is absoluut. Houd altijd rekening met de juiste "+" en "–" aansluitingen.

- Gebruik lagere spanningen (12 V) voor wisselaandrijvingen  
- Gebruik hogere spanningen (tot 18 V) voor magneetaandrijvingen

---

## 🧩 Aansluitingen

- 🔌 DCC IN – Ingang voor het DCC-commandosignaal  
- ⚡ POW + / POW - – Voedings­ingangen voor elke uitgangsectie  
- ⚙️ OUT A / OUT B – Aandrijfuitgangen voor spoelen, motoren of relais  
- 🔌 Doorlus­aansluitingen – U kunt meer Duplex-decoders aansluiten op de volgende sockets  
- U kunt tot vier relais­modules aansluiten



*Afbeelding 1: Hoofd­voedings­aansluitingen*



*Afbeelding 2: 2 Duplex-decoders in serie geschakeld*



*Afbeelding 3: 2 dubbele relais­modules aangesloten*



*Afbeelding 4: Voorbeeld 1 — dubbele magneetaandrijving en dubbele relaismodule*



*Afbeelding 5: Voorbeeld met 2x MTB MP-1*

---

## 🎚️ DIP-schakelaar­configuratie

Vijf DIP-schakelaars bepalen alle bedrijfsmodi:

1️⃣ Uitgang A – Modusselectie: Enkele / Dubbele uitgang  
2️⃣ Uitgang A – Pulsmodus: Puls (typisch voor magneet) of Continu (motor)  
3️⃣ Uitgang B – Modusselectie: Enkele / Dubbele uitgang  
4️⃣ Uitgang B – Pulsmodus: Puls of Continu  
5️⃣ Koppelschakelaar – Koppelt uitgang B aan uitgang A (slave-modus). Alleen actief als A is ingesteld op dubbele modus



---

## ⚙️ Bedrijfslogica

### 🅰️ Uitgang A (primair)
- Werkt als enkele of dubbele uitgang  
- In dubbele modus bestuurt één DCC-adres beide uitgangen, of ze nu gepulst of continu zijn  
- In enkele modus gebruikt elke uitgang zijn eigen adres  

### 🅱️ Uitgang B (secundair)
- Kan onafhankelijk werken zoals A of als slave van A  
- In gekoppelde werking kan B automatisch de hartpunt­polarisering afhandelen; het schakelt de relais en de wisselaandrijving in een specifieke volgorde om kortsluiting te voorkomen:
    1. Hartpunt spanningsloos maken
    2. Wissel omzetten
    3. Hartpunt opnieuw van spanning voorzien met omgekeerde polariteit

Deze volgorde ondersteunt Electrofrog- en Unifrog-banen

---

## 🔗 Slave-modus uitbreidingen

### Seinmodus

Wanneer de koppeling tussen de uitgangen is ingeschakeld, verandert uitgang B van gedrag afhankelijk van de modus van A:
- Als A Enkel + Puls is, accepteert de decoder DCC EXT-commando's voor seinen met 4 lampen  
- Beide uitgangen werken samen als een kleine seinregelaar  
- De Duplex heeft geen concept van vaste instellingen, seinen­aspecten of voorinstellingen voor seinen. In plaats daarvan gebruiken we de DCC EXT-commando's waarmee we een waarde van 0–255 naar de decoder kunnen sturen.

De waarde werkt binair. 255 heeft een binaire waarde van `1111 1111`. De hoge nibble (eerste 4 bits) geeft aan welke LED's moeten knipperen; de lage nibble (laatste 4 bits) geeft aan welke lampen aan of uit moeten zijn. Wanneer een lamp via de hoge nibble is ingesteld om te knipperen, moet het overeenkomstige bit in de lage nibble `0` zijn. **Bijvoorbeeld, wanneer alleen de eerste twee lampen moeten knipperen, de derde lamp uit is, en de vierde lamp aan is: de waarde is `1100 0001` = 193 decimaal.**



De software die u voor uw modelbaan gebruikt, moet de seinen­aspecten koppelen aan DCC EXT-waarden. Schrijf de binaire waarde op voor elk gewenst aspect en bereken vervolgens het decimale equivalent. De ingebouwde Calculator-app van Windows kan helpen — schakel deze eerst over naar de **Programmeur**-modus.



Als voorbeeld nemen we een Nederlands hoofdlijn­sein. We verbinden groen met A1, geel met A2, rood met B1 en het cijfervak met B2. Paars is de gemeenschappelijke +-draad.

alt tekst

Dit sein gebruikt de volgende aspecten.

| Aspect | Lampen (G/Y/R/W) | Hoge nibble (knipperbits) | Lage nibble (aan/uit bits) | Decimaal |
|---|---|---|---|---|
| Stop | R | 0000 | 0100 | 4 |
| Doorrijden | G | 0000 | 0001 | 1 |
| Voorzichtig / Verwacht stop | Y | 0000 | 0010 | 2 |
| Op zicht rijden (Y knippert) | Y (knippert) | 0010 | 0000 | 32 |
| Afwijkende rijweg / snelheidsroute (G knippert) | G (knippert) | 0001 | 0000 | 16 |
| Snelheid aangegeven bij dit sein (G knippert + W AAN) | G (knippert) + W AAN | 0001 | 1000 | 24 |
| Naderen met snelheid bij volgend sein (Y + W AAN) | Y AAN + W AAN | 0000 | 1010 | 10 |

---

## 💡 Technische opmerkingen

- Compatibel met Roco, NMRA en uitgebreide DCC-adressering  
- Elke uitgang kan standaard wisselspolen of kleine motoren veilig aansturen  
- EEPROM slaat de laatste configuratie en adressen op  
- Firmware ondersteunt adres­leren via DCC-commando of drukknop (indien geïmplementeerd)

---

## 🧰 Veiligheid en aanbevelingen

- Controleer altijd de juiste voedings­polariteit vóór het inschakelen  
- Overschrijd 18 V DC niet  
- Zorg voor voldoende ruimte bij het gelijktijdig aansturen van vier hoog­stroom­relais  
- Gebruik een goede DC-voeding met stroomcapaciteit die overeenkomt met uw wisseltype

---

## Bijlage A, DIP-schakelaar­combinaties

### Afzonderlijke uitgangen        

| DIP-schakelaars | Beschrijving |
|---|---|
| 00000 | A = Dubbele puls, B = Dubbele puls |
| 00010 | A = Dubbele puls, B = Dubbel continu |
| 00110 | A = Dubbele puls, B = Enkel continu |
| 01000 | A = Dubbel continu, B = Dubbele puls |
| 01010 | A = Dubbel continu, B = Dubbel continu |
| 01110 | A = Dubbel continu, B = Enkel continu |
| 11000 | A = Enkel continu, B = Dubbele puls |
| 11010 | A = Enkel continu, B = Dubbel continu |
| 11110 | A = Enkel continu, B = Enkel continu |

### Uitgang B gekoppeld aan uitgang A

| DIP-schakelaars | Beschrijving |
|---|---|
| 00001 | A = Dubbele puls, B = Dubbel relais |
| 00101 | A = Dubbele puls, B = Enkel relais |
| 01001 | A = Dubbel continu, B = Dubbel relais |
| 01101 | A = Dubbel continu, B = Enkel relais |
| 10001 | Seinmodus |

---

📘 *Einde van de handleiding*

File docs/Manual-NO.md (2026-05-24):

> 🌐 &nbsp; [🇬🇧 EN](Manual-EN.md) &nbsp;|&nbsp; [🇩🇪 DE](Manual-DE.md) &nbsp;|&nbsp; [🇫🇷 FR](Manual-FR.md) &nbsp;|&nbsp; [🇳🇱 NL](Manual-NL.md) &nbsp;|&nbsp; [🇪🇸 ES](Manual-ES.md) &nbsp;|&nbsp; [🇮🇹 IT](Manual-IT.md) &nbsp;|&nbsp; [🇵🇱 PL](Manual-PL.md) &nbsp;|&nbsp; [🇨🇿 CS](Manual-CS.md) &nbsp;|&nbsp; [🇩🇰 DA](Manual-DA.md) &nbsp;|&nbsp; 🇳🇴 NO &nbsp;|&nbsp; [🇸🇪 SV](Manual-SV.md) &nbsp;|&nbsp; [🇭🇺 HU](Manual-HU.md) &nbsp;|&nbsp; [🇵🇹 PT](Manual-PT.md)

# ⚙️ OS-Duplex Dekoder-manual

**Dobbel DCC-dekoder for solenoider, reléer og sporskiftemotorer**



---

## 🔧 Innledning

OS-Duplex er en dobbel DCC-tilbehørsdekoder utviklet for alle typer sporskiftedrev — fra tradisjonelle solenoider til motordrev og relé-moduler for frog-polarisering.  
Hver side (A og B) kan operere uavhengig eller kobles sammen.

Hver side kan fungere som enten:
- 🅰️ / 🅱️ to uavhengige enkelutganger (hver med sin egen DCC-adresse), eller
- ⚙️ én kombinert dobbeltutgang for et dobbeltspoleanlegg eller motordrevet sporskifte.

Valgfrie reléfester gjør det mulig å legge til frog-polarisering, eller bruke de samme utgangene til å drive ekstra spoler eller motorer.

---

## ⚡ Strømforsyning

OS-Duplex krever en ekstern DC-strømforsyning mellom 12 V og 18 V DC.  
⚠️ Polariteten er absolutt. Overhold alltid riktige «+»- og «–»-tilkoblinger.

- Bruk lavere spenninger (12 V) for sporskiftemotordrev  
- Bruk høyere spenninger (opptil 18 V) for spoledrev

---

## 🧩 Tilkoblinger

- 🔌 DCC IN – Inngang for DCC-kommandosignal  
- ⚡ POW + / POW - – Strøminnganger for hvert utgangsavsnitt  
- ⚙️ OUT A / OUT B – Drivutganger for spoler, motorer eller reléer  
- 🔌 Gjennomkoblingskontakter – Du kan plugge inn flere Duplex-dekodere i de følgende soklene  
- Du kan plugge inn opptil fire relé-moduler



*Figur 1: Primære strømterminaler*



*Figur 2: 2 Duplex-dekodere koblet i kjede*



*Figur 3: 2 doble relé-moduler plugget inn*



*Figur 4: Eksempel 1 – Dobbelt spoledrev og dobbelt relé-modul*



*Figur 5: Eksempel med 2× MTB MP-1*

---

## 🎚️ DIP-bryter-konfigurasjon

Fem DIP-brytere definerer alle driftsmodus:

1️⃣ Utgang A – Modusvalg: Enkel / Dobbel utgang  
2️⃣ Utgang A – Pulsmodus: Puls (typisk spole) eller Kontinuerlig (motor)  
3️⃣ Utgang B – Modusvalg: Enkel / Dobbel utgang  
4️⃣ Utgang B – Pulsmodus: Puls eller Kontinuerlig  
5️⃣ Koblingsbryter – Kobler Utgang B til Utgang A (slavemodus). Kun aktiv hvis A er satt til Dobbel modus



---

## ⚙️ Driftslogikk

### 🅰️ Utgang A (primær)
- Fungerer som enkel eller dobbel utgang
- I dobbel modus styrer én DCC-adresse begge utganger, enten de pulses eller er stasjonære
- I enkel modus bruker hver utgang sin egen adresse

### 🅱️ Utgang B (sekundær)
- Kan kjøres uavhengig som A, eller som slave til A
- I koblet drift kan B automatisk håndtere frog-polarisering; den bytter reléene og sporskiftemotoren i en bestemt rekkefølge for å unngå kortslutning:
    1. Fjern spenning fra frog
    2. Bytt sporskifte
    3. Sett spenning på frog igjen med motsatt polaritet

Denne timingen støtter Electrofrog- og Uni-frog-anlegg

---

## 🔗 Slave-modus-utvidelser

### Signalmodus

Når koblingen mellom utgangene er aktivert, endrer Utgang B oppførsel avhengig av A sin modus:
- Hvis A er Enkel + Puls, aksepterer dekoderen DCC EXT-kommandoer for 4-lampe-signaler  
- Begge utganger fungerer sammen som en miniatyr signalstyrer  
- Duplex har ingen konsept om faste innstillinger, aspekter eller forhåndsinnstillinger for signaler. I stedet bruker vi DCC EXT-kommandoer, med hvilke vi kan sende en verdi fra 0–255 til dekoderen.

Verdien fungerer i binær. 255 har binærverdien `1111 1111`. Den høye nibble-en (de første 4 bitene) angir hvilke LED-er som skal blinke; den lave nibble-en (de siste 4 bitene) angir hvilke lys som skal være på eller av. Når et lys er satt til å blinke via den høye nibble-en, må tilsvarende bit i den lave nibble-en være `0`. **For eksempel, når bare de to første lysene skal blinke, det tredje lyset er av og det fjerde lyset er på: verdien er `1100 0001` = 193 desimal.**



Programvaren du bruker for modelljernbaneanlegget ditt må koble signalaspektene til DCC EXT-verdier. Skriv ned binærverdien for hvert ønsket aspekt og beregn deretter desimalverdien. Windows' innebygde Kalkulator-app kan hjelpe — bytt den til **Programmerer**-modus først.



Som eksempel bruker vi et nederlandsk hovedlinjessignal. Vi kobler grønn til A1, gul til A2, rød til B1 og nummerboksen til B2. Lilla er den felles +-ledningen



Dette signalet bruker disse aspektene.

| Aspekt | Lamper (G/Y/R/W) | Høy nibble (blinke-biter) | Lav nibble (på/av-biter) | Desimal |
|---|---|---|---|---|
| Stopp | R | 0000 | 0100 | 4 |
| Kjør | G | 0000 | 0001 | 1 |
| Forsiktighet / Forvent stopp | Y | 0000 | 0010 | 2 |
| Kjør med sikt (Y blinker) | Y (blink) | 0010 | 0000 | 32 |
| Avvik / hastigheitsrute (G blinker) | G (blink) | 0001 | 0000 | 16 |
| Hastighet angitt ved dette signalet (G blinker + W PÅ) | G (blink) + W PÅ | 0001 | 1000 | 24 |
| Nærm deg med hastighet ved neste signal (Y + W PÅ) | Y PÅ + W PÅ | 0000 | 1010 | 10 |

---

## 💡 Tekniske merknader

- Kompatibel med Roco, NMRA og utvidet DCC-adressering
- Hver utgang kan trygt forsyne standard sporskiftespoler eller små motorer
- EEPROM lagrer siste konfigurasjon og adresser
- Firmware støtter adresselæring via DCC-kommando eller knappeinntasting (hvis implementert)

---

## 🧰 Sikkerhet og anbefalinger

- Verifiser alltid korrekt forsyningspolaritet før oppstart
- Ikke overskrid 18 V DC
- Sørg for tilstrekkelig avstand ved drift av fire høystrømsreléer samtidig
- Bruk en egnet DC-forsyning med strømkapasitet tilpasset sporskiftetypen din

---

## Tillegg A, DIP-bryter-kombinasjoner

### Individuelle utganger        

| Dipbrytere | Beskrivelse |
|---|---|
| 00000 | A = Dobbel puls, B = Dobbel puls |
| 00010 | A = Dobbel puls, B = Dobbel stasjonær |
| 00110 | A = Dobbel puls, B = Enkel stasjonær |
| 01000 | A = Dobbel stasjonær, B = Dobbel puls |
| 01010 | A = Dobbel stasjonær, B = Dobbel stasjonær |
| 01110 | A = Dobbel stasjonær, B = Enkel stasjonær |
| 11000 | A = Enkel stasjonær, B = Dobbel puls |
| 11010 | A = Enkel stasjonær, B = Dobbel stasjonær |
| 11110 | A = Enkel stasjonær, B = Enkel stasjonær |

### Utgang B koblet til utgang A

| Dipbrytere | Beskrivelse |
|---|---|
| 00001 | A = Dobbel puls, B = Dobbelt relé |
| 00101 | A = Dobbel puls, B = Enkelt relé |
| 01001 | A = Dobbel stasjonær, B = Dobbelt relé |
| 01101 | A = Dobbel stasjonær, B = Enkelt relé |
| 10001 | Signalmodus |

---

📘 *Slutt på manual*

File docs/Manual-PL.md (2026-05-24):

> 🌐 &nbsp; [🇬🇧 EN](Manual-EN.md) &nbsp;|&nbsp; [🇩🇪 DE](Manual-DE.md) &nbsp;|&nbsp; [🇫🇷 FR](Manual-FR.md) &nbsp;|&nbsp; [🇳🇱 NL](Manual-NL.md) &nbsp;|&nbsp; [🇪🇸 ES](Manual-ES.md) &nbsp;|&nbsp; [🇮🇹 IT](Manual-IT.md) &nbsp;|&nbsp; 🇵🇱 PL &nbsp;|&nbsp; [🇨🇿 CS](Manual-CS.md) &nbsp;|&nbsp; [🇩🇰 DA](Manual-DA.md) &nbsp;|&nbsp; [🇳🇴 NO](Manual-NO.md) &nbsp;|&nbsp; [🇸🇪 SV](Manual-SV.md) &nbsp;|&nbsp; [🇭🇺 HU](Manual-HU.md) &nbsp;|&nbsp; [🇵🇹 PT](Manual-PT.md)

# ⚙️ Instrukcja dekodera OS-Duplex

**Podwójny dekoder DCC do solenoidów, przekaźników i silników zwrotnic**



---

## 🔧 Wprowadzenie

OS-Duplex to dwukanałowy akcesoria dekoder DCC przeznaczony do wszystkich typów napędów zwrotnicowych — od tradycyjnych solenoidów po napędy silnikowe i moduły przekaźnikowe do polaryzacji sercówek.  
Każda strona (A i B) może pracować niezależnie lub być ze sobą połączona.

Każda strona może działać jako:
- 🅰️ / 🅱️ dwa niezależne pojedyncze wyjścia (każde z własnym adresem DCC), lub
- ⚙️ jedno połączone podwójne wyjście dla napędu zwrotnicy z podwójną cewką lub napędu silnikowego.

Opcjonalne gniazda przekaźnikowe umożliwiają dodanie polaryzacji sercówki lub użycie tych samych wyjść do sterowania dodatkowymi cewkami lub silnikami.

---

## ⚡ Zasilanie

OS-Duplex wymaga zewnętrznego zasilania DC między 12 V a 18 V DC.  
⚠️ Biegunowość jest bezwzględna. Zawsze zachowuj prawidłowe podłączenie „+" i „–".

- Używaj niższych napięć (12 V) do napędów silnikowych zwrotnic  
- Używaj wyższych napięć (do 18 V) do napędów cewkowych

---

## 🧩 Podłączenia

- 🔌 DCC IN – Wejście sygnału polecenia DCC  
- ⚡ POW + / POW - – Wejścia zasilania dla każdej sekcji wyjściowej  
- ⚙️ OUT A / OUT B – Wyjścia sterujące cewkami, silnikami lub przekaźnikami  
- 🔌 Złącza przelotowe – Możesz podłączyć kolejne dekodery Duplex w następnych gniazdach  
- Możesz podłączyć do czterech modułów przekaźnikowych



*Rysunek 1: Główne zaciski zasilające*



*Rysunek 2: 2 dekodery Duplex połączone łańcuchowo*



*Rysunek 3: 2 podwójne moduły przekaźnikowe podłączone*



*Rysunek 4: Przykład 1 — napęd podwójną cewką i podwójny moduł przekaźnikowy*



*Rysunek 5: Przykład z 2× MTB MP-1*

---

## 🎚️ Konfiguracja przełączników DIP

Pięć przełączników DIP definiuje wszystkie tryby pracy:

1️⃣ Wyjście A – Wybór trybu: pojedyncze / podwójne wyjście  
2️⃣ Wyjście A – Tryb impulsowy: impuls (typowa cewka) lub ciągły (silnik)  
3️⃣ Wyjście B – Wybór trybu: pojedyncze / podwójne wyjście  
4️⃣ Wyjście B – Tryb impulsowy: impuls lub ciągły  
5️⃣ Przełącznik łączący – Łączy wyjście B z wyjściem A (tryb slave). Aktywny tylko jeśli A jest ustawione na tryb podwójny



---

## ⚙️ Logika działania

### 🅰️ Wyjście A (główne)
- Działa jako pojedyncze lub podwójne wyjście
- W trybie podwójnym jeden adres DCC steruje oboma wyjściami, niezależnie od tego, czy są impulsowane, czy ciągłe
- W trybie pojedynczym każde wyjście używa własnego adresu

### 🅱️ Wyjście B (pomocnicze)
- Może działać niezależnie jak A lub jako slave wyjścia A
- W trybie powiązanym B może automatycznie obsługiwać polaryzację sercówki; przełącza przekaźniki i silnik zwrotnicy w określonej kolejności, aby zapobiec zwarciom:
    1. Odłączenie zasilania sercówki
    2. Przełączenie zwrotnicy
    3. Ponowne zasilenie sercówki z przeciwną biegunowością

Ta sekwencja obsługuje układy z Electrofrog i Uni-frog

---

## 🔗 Rozszerzenia trybu slave

### Tryb semaforowy

Gdy łącze między wyjściami jest aktywne, wyjście B zmienia zachowanie w zależności od trybu A:
- Jeśli A jest w trybie pojedynczym + impulsowym, dekoder akceptuje rozszerzone polecenia DCC EXT dla semaforów 4-lampowych  
- Oba wyjścia działają razem jako miniaturowy sterownik semafora  
- OS-Duplex nie posiada pojęcia stałych ustawień, aspektów ani szablonów dla semaforów. Zamiast tego używamy poleceń DCC EXT, za pomocą których możemy przesłać do dekodera wartość 0–255.

Wartość działa w systemie binarnym. 255 ma wartość binarną `1111 1111`. Wysoka tetrada (pierwsze 4 bity) określa, które LED powinny migać; niska tetrada (ostatnie 4 bity) określa, które lampki powinny być włączone lub wyłączone. Gdy lampka jest ustawiona na miganie przez wysoką tetradę, odpowiadający jej bit w niskiej tetradzie musi wynosić `0`. **Na przykład, gdy tylko pierwsze dwie lampki powinny migać, trzecia jest wyłączona, a czwarta jest włączona: wartość to `1100 0001` = 193 dziesiętnie.**



Oprogramowanie używane do sterowania makietą kolejową musi powiązać aspekty semafora z wartościami DCC EXT. Zapisz wartość binarną każdego żądanego aspektu, a następnie oblicz jej odpowiednik dziesiętny. Pomocny może być wbudowany kalkulator systemu Windows — przełącz go najpierw w tryb **Programista**.



Jako przykład weźmiemy holenderski semafory linii głównej. Podłączamy zielony do A1, żółty do A2, czerwony do B1, a skrzynkę numeryczną do B2. Fioletowy to wspólny przewód +.

tekst alternatywny

Ten semafor używa następujących aspektów.

| Aspekt | Lampki (G/Y/R/W) | Wysoka tetrada (bity migania) | Niska tetrada (bity wł./wył.) | Dziesiętnie |
|---|---|---|---|---|
| Stój | R | 0000 | 0100 | 4 |
| Jedź | G | 0000 | 0001 | 1 |
| Ostrożnie / Oczekuj zatrzymania | Y | 0000 | 0010 | 2 |
| Jedź z ograniczoną prędkością (Y miga) | Y (miga) | 0010 | 0000 | 32 |
| Odgałęzienie / trasa z prędkością (G miga) | G (miga) | 0001 | 0000 | 16 |
| Prędkość wskazana na tym semaforze (G miga + W wł.) | G (miga) + W wł. | 0001 | 1000 | 24 |
| Dojedź z prędkością do następnego semafora (Y + W wł.) | Y wł. + W wł. | 0000 | 1010 | 10 |

---

## 💡 Uwagi techniczne

- Kompatybilny z adresowaniem DCC Roco, NMRA i rozszerzonym
- Każde wyjście może bezpiecznie zasilać standardowe cewki zwrotnicowe lub małe silniki
- EEPROM przechowuje ostatnią konfigurację i adresy
- Oprogramowanie układowe obsługuje uczenie adresów przez polecenie DCC lub przycisk (jeśli zaimplementowano)

---

## 🧰 Bezpieczeństwo i zalecenia

- Przed włączeniem zasilania zawsze sprawdź prawidłową biegunowość zasilacza
- Nie przekraczaj 18 V DC
- Zachowaj odpowiednie odstępy przy jednoczesnym sterowaniu czterema przekaźnikami dużych prądów
- Używaj odpowiedniego zasilacza DC o wydajności prądowej dostosowanej do rodzaju zwrotnicy

---

## Załącznik A — kombinacje przełączników DIP

### Niezależne wyjścia        

| Przełączniki DIP | Opis |
|---|---|
| 00000 | A = Double Pulse, B = Double Pulse |
| 00010 | A = Double Pulse, B = Double Steady |
| 00110 | A = Double Pulse, B = Single Steady |
| 01000 | A = Double Steady, B = Double Pulse |
| 01010 | A = Double Steady, B = Double Steady |
| 01110 | A = Double Steady, B = Single Steady |
| 11000 | A = Single Steady, B = Double Pulse |
| 11010 | A = Single Steady, B = Double Steady |
| 11110 | A = Single Steady, B = Single Steady |

### Wyjście B powiązane z wyjściem A

| Przełączniki DIP | Opis |
|---|---|
| 00001 | A = Double Pulse, B = Double Relay |
| 00101 | A = Double Pulse, B = Single Relay |
| 01001 | A = Double Steady, B = Double Relay |
| 01101 | A = Double Steady, B = Single Relay |
| 10001 | Tryb semaforowy |

---

📘 *Koniec instrukcji*

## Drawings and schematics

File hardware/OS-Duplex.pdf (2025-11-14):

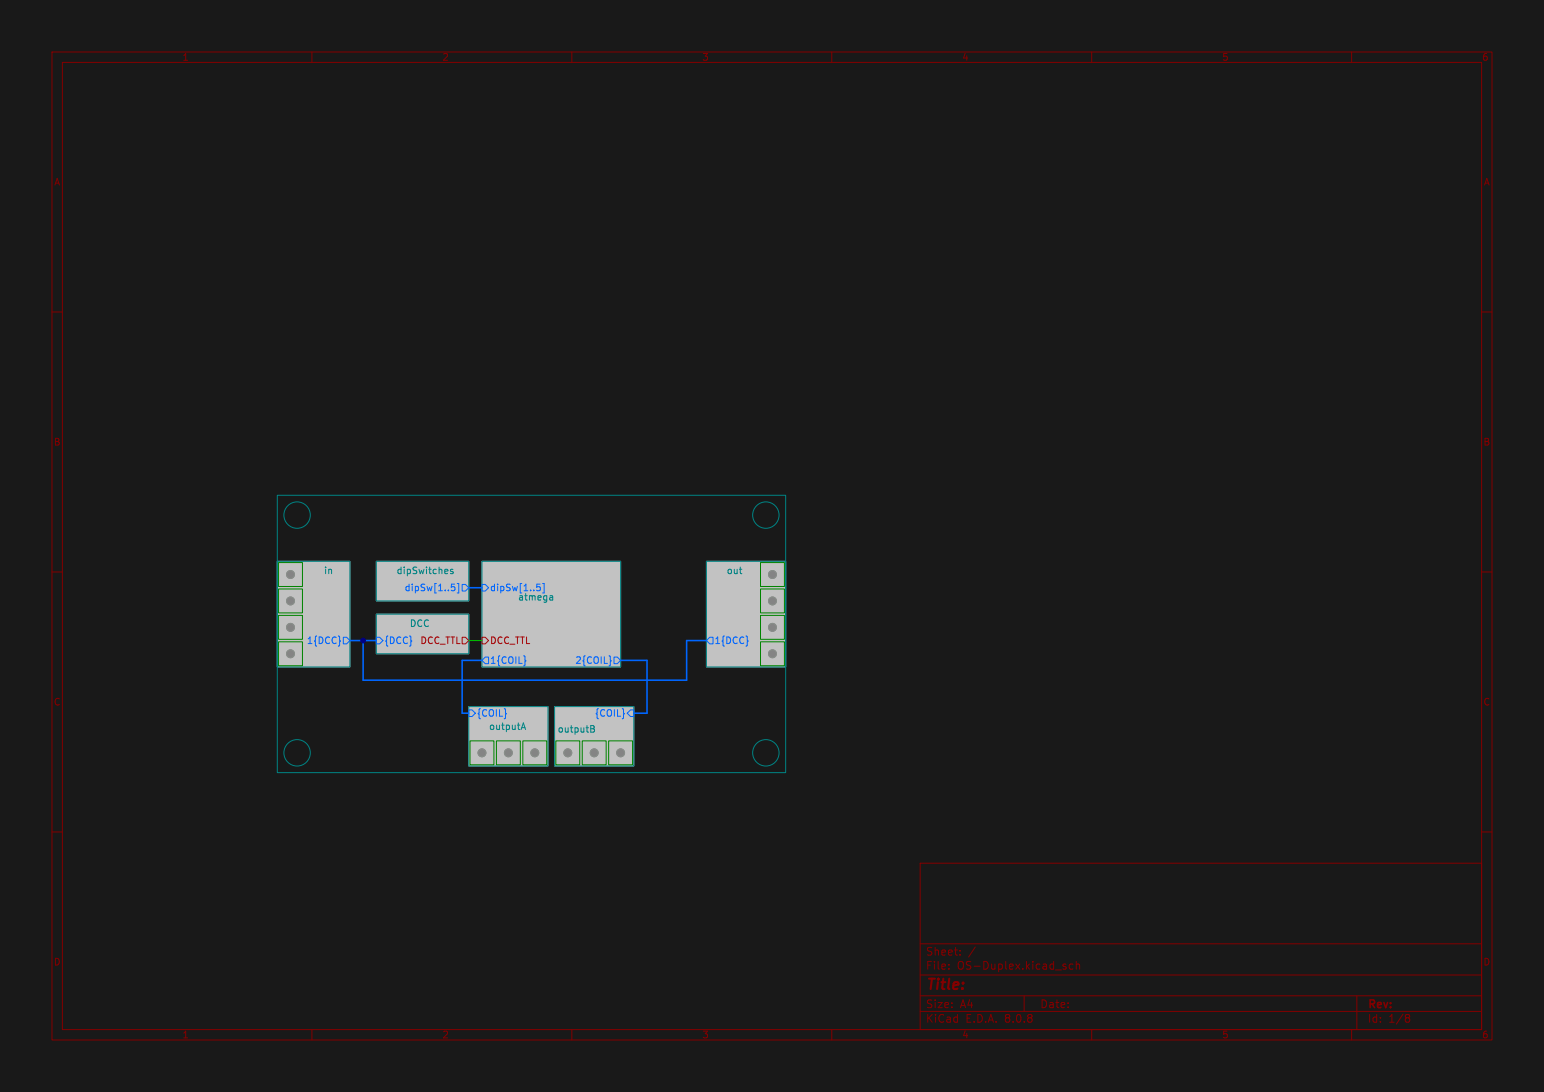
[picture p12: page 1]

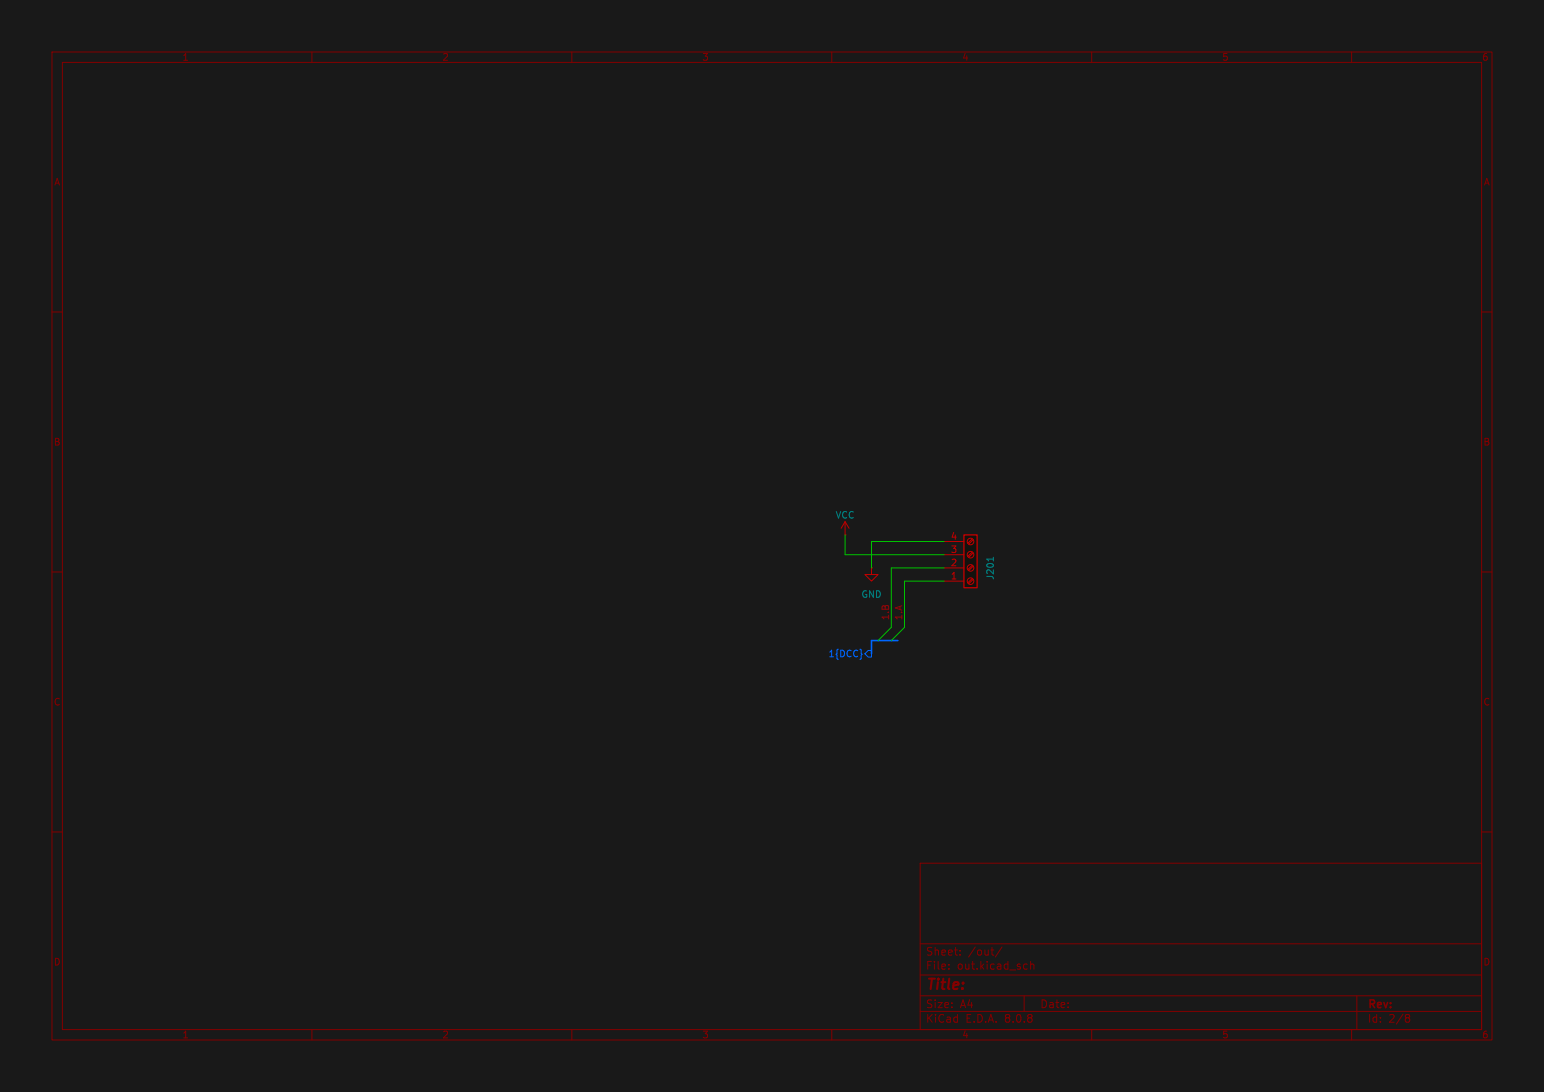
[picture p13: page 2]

Id: 2/8 Title: File: out.kicad_sch Sheet: /out/ GND

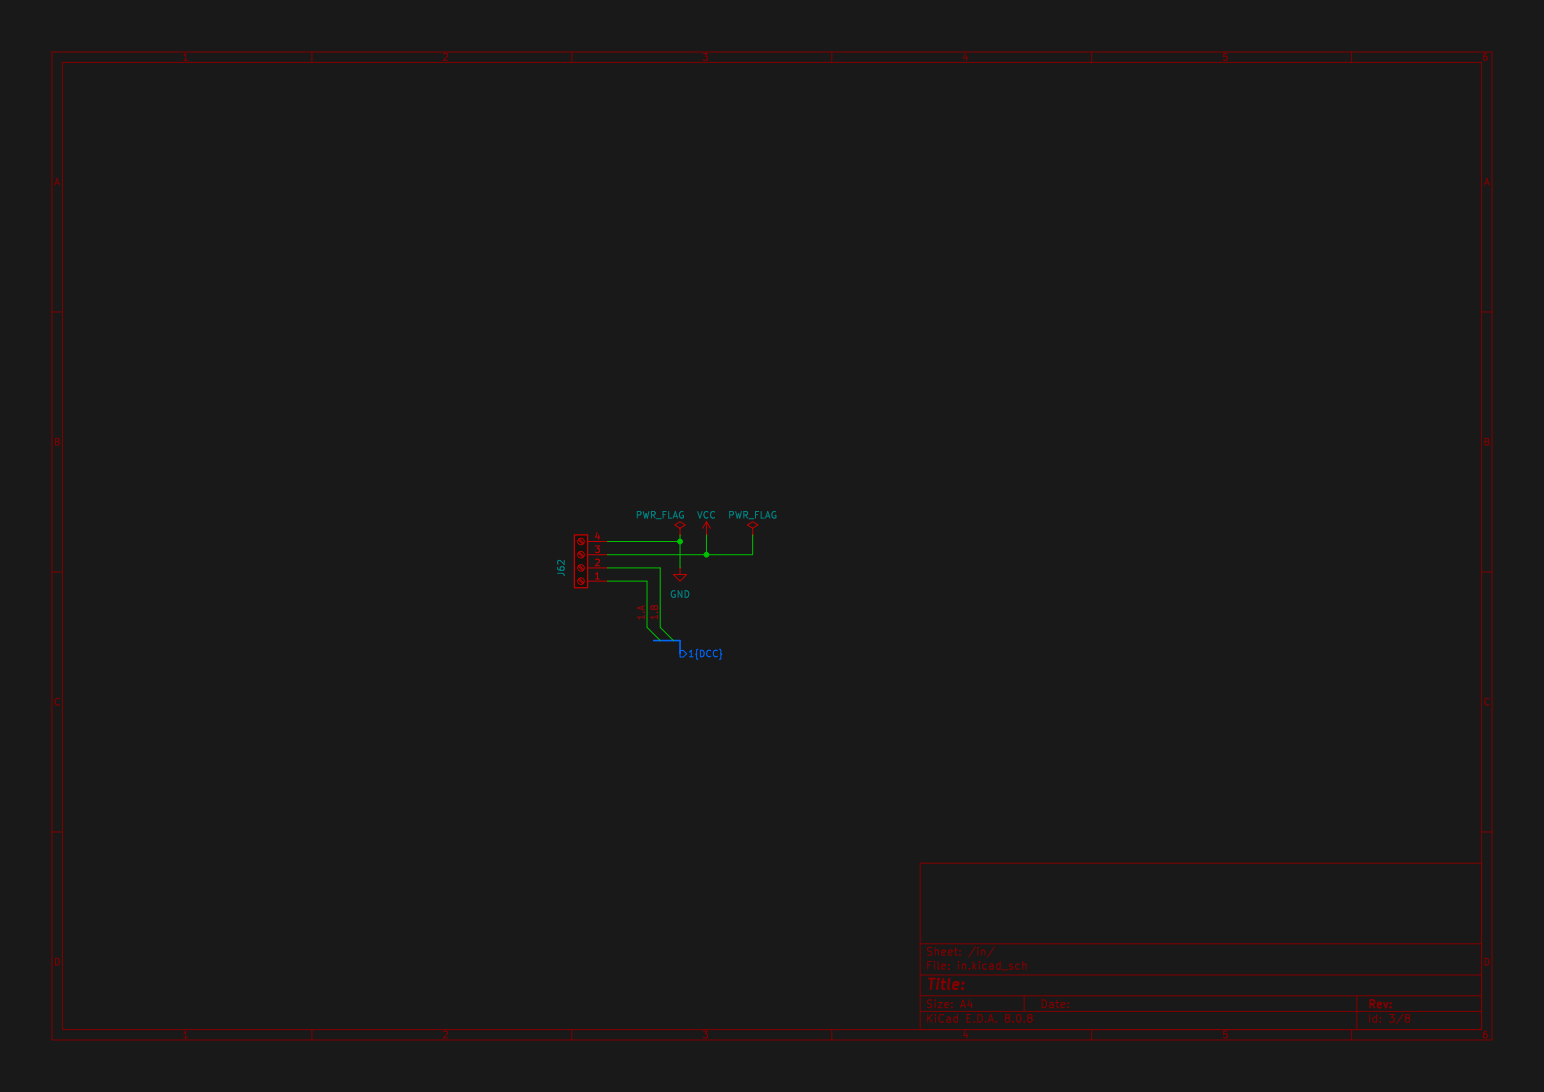
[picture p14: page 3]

Id: 3/8 Title: File: in.kicad_sch Sheet: /in/

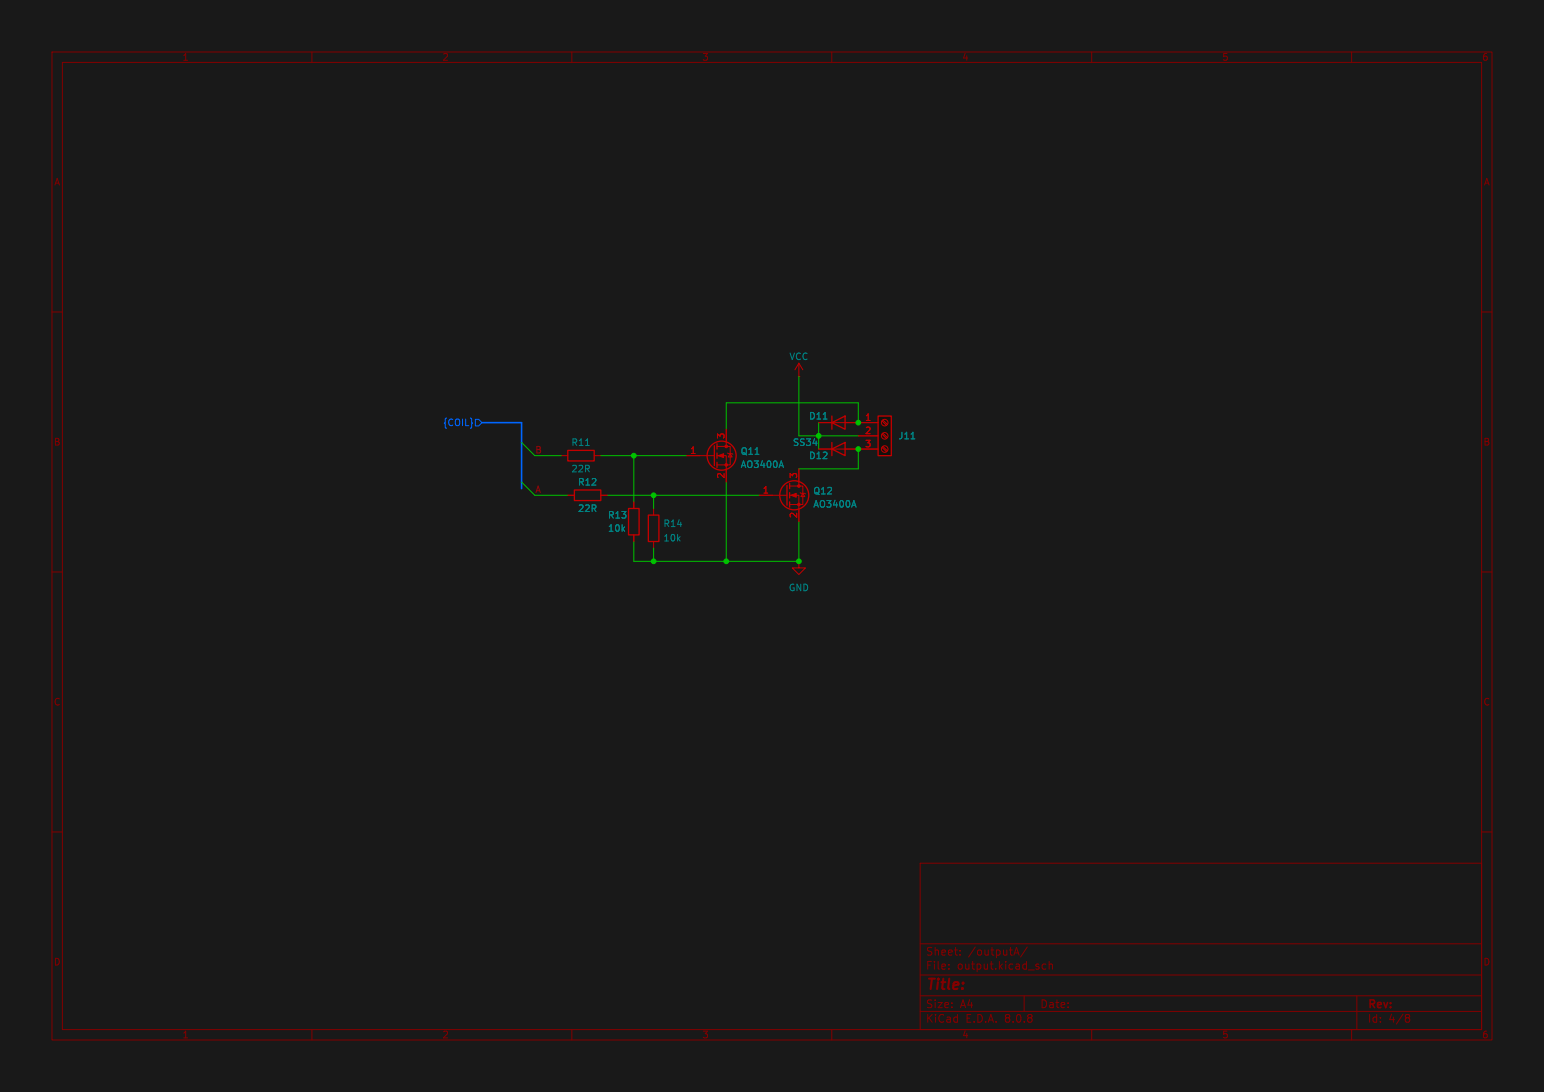
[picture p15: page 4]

Id: 4/8 Title: File: output.kicad_sch Sheet: /outputA/

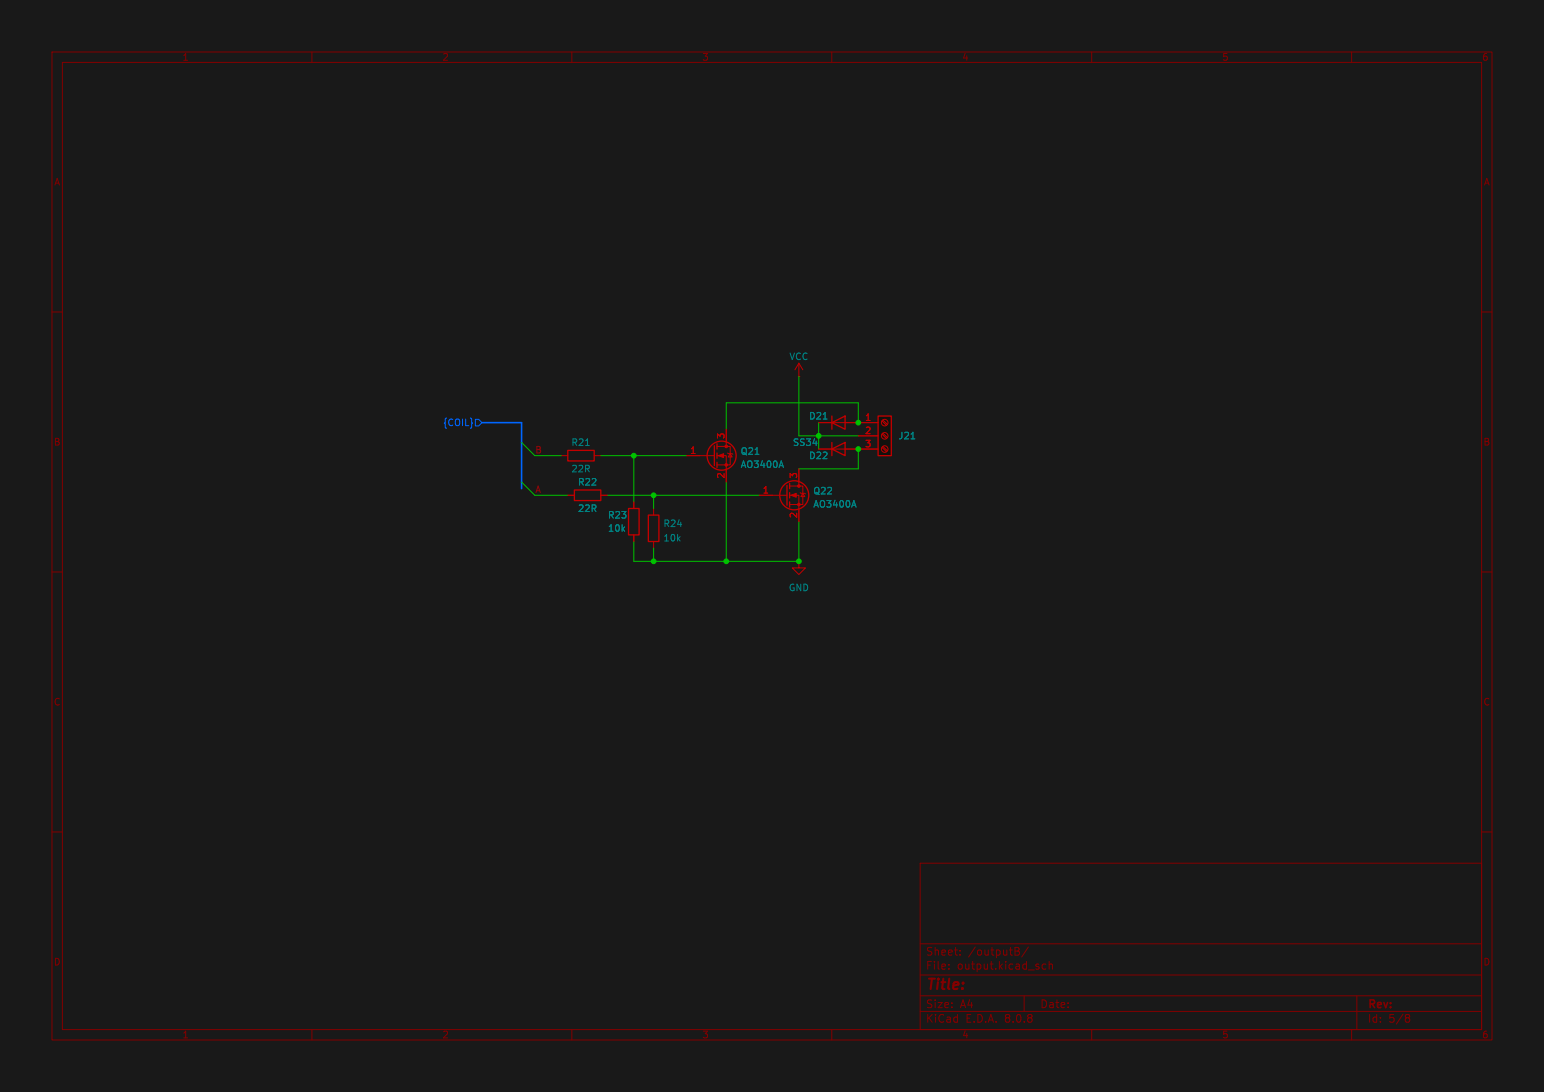
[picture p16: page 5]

Id: 5/8 Title: File: output.kicad_sch Sheet: /outputB/

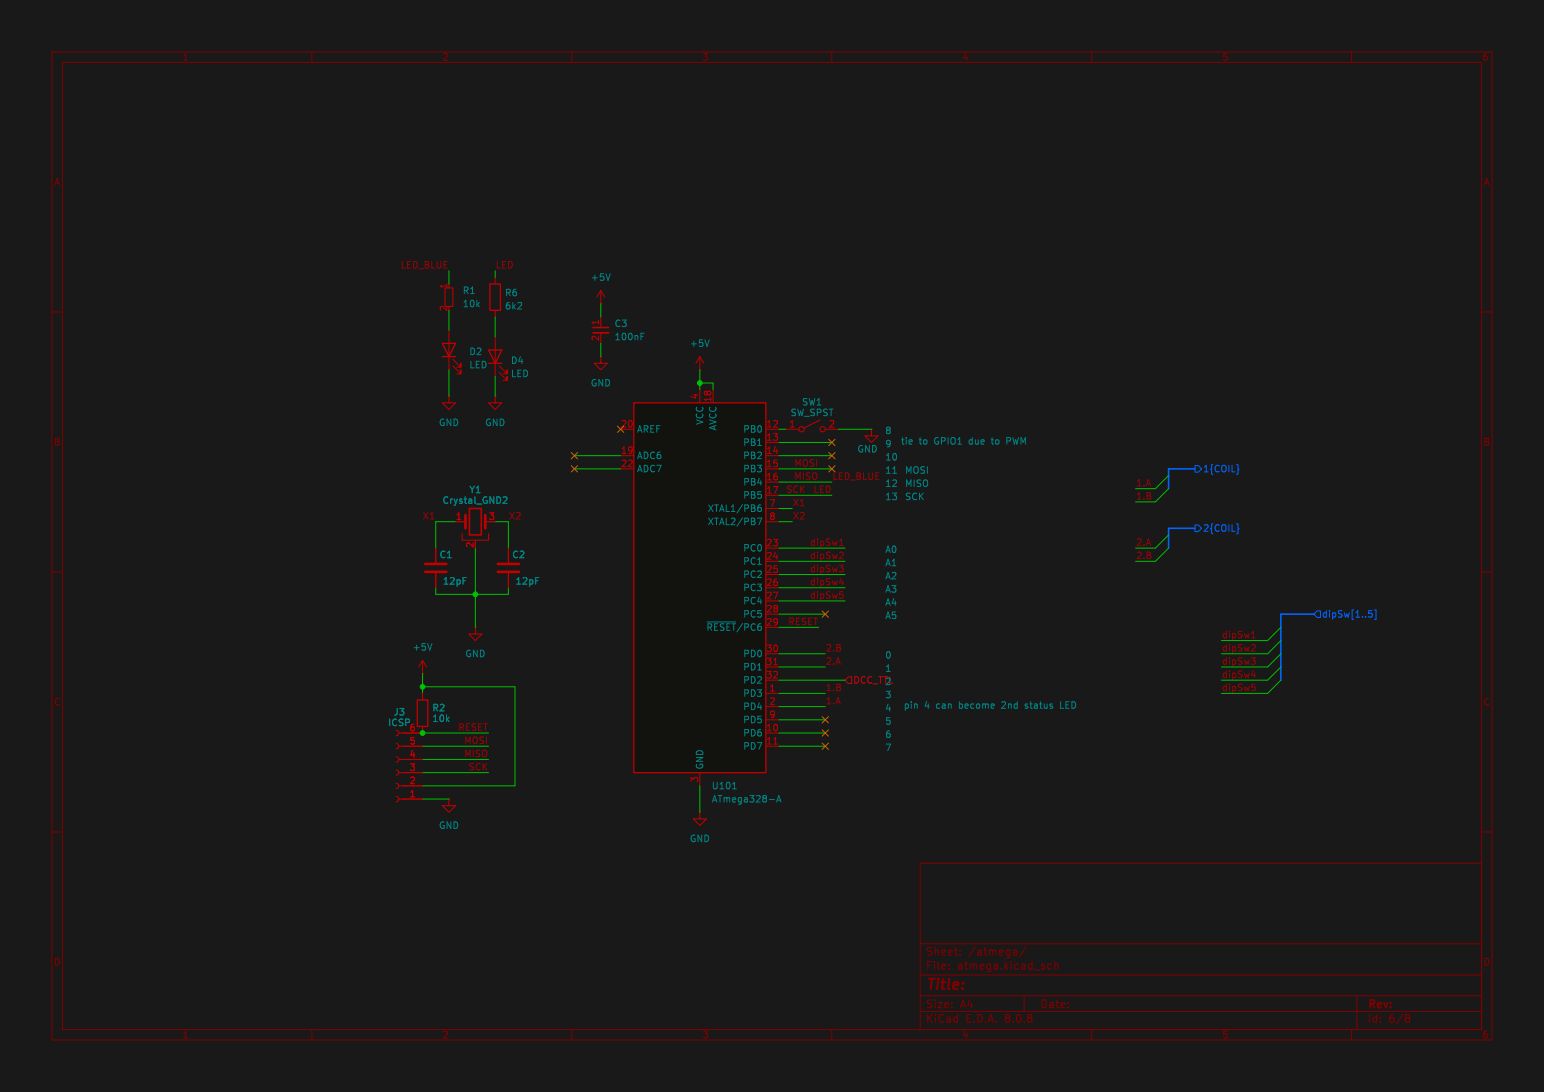
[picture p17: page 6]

tie to GPIO1 due to PWM
10 MISO

pin 4 can become 2nd status LED 2476

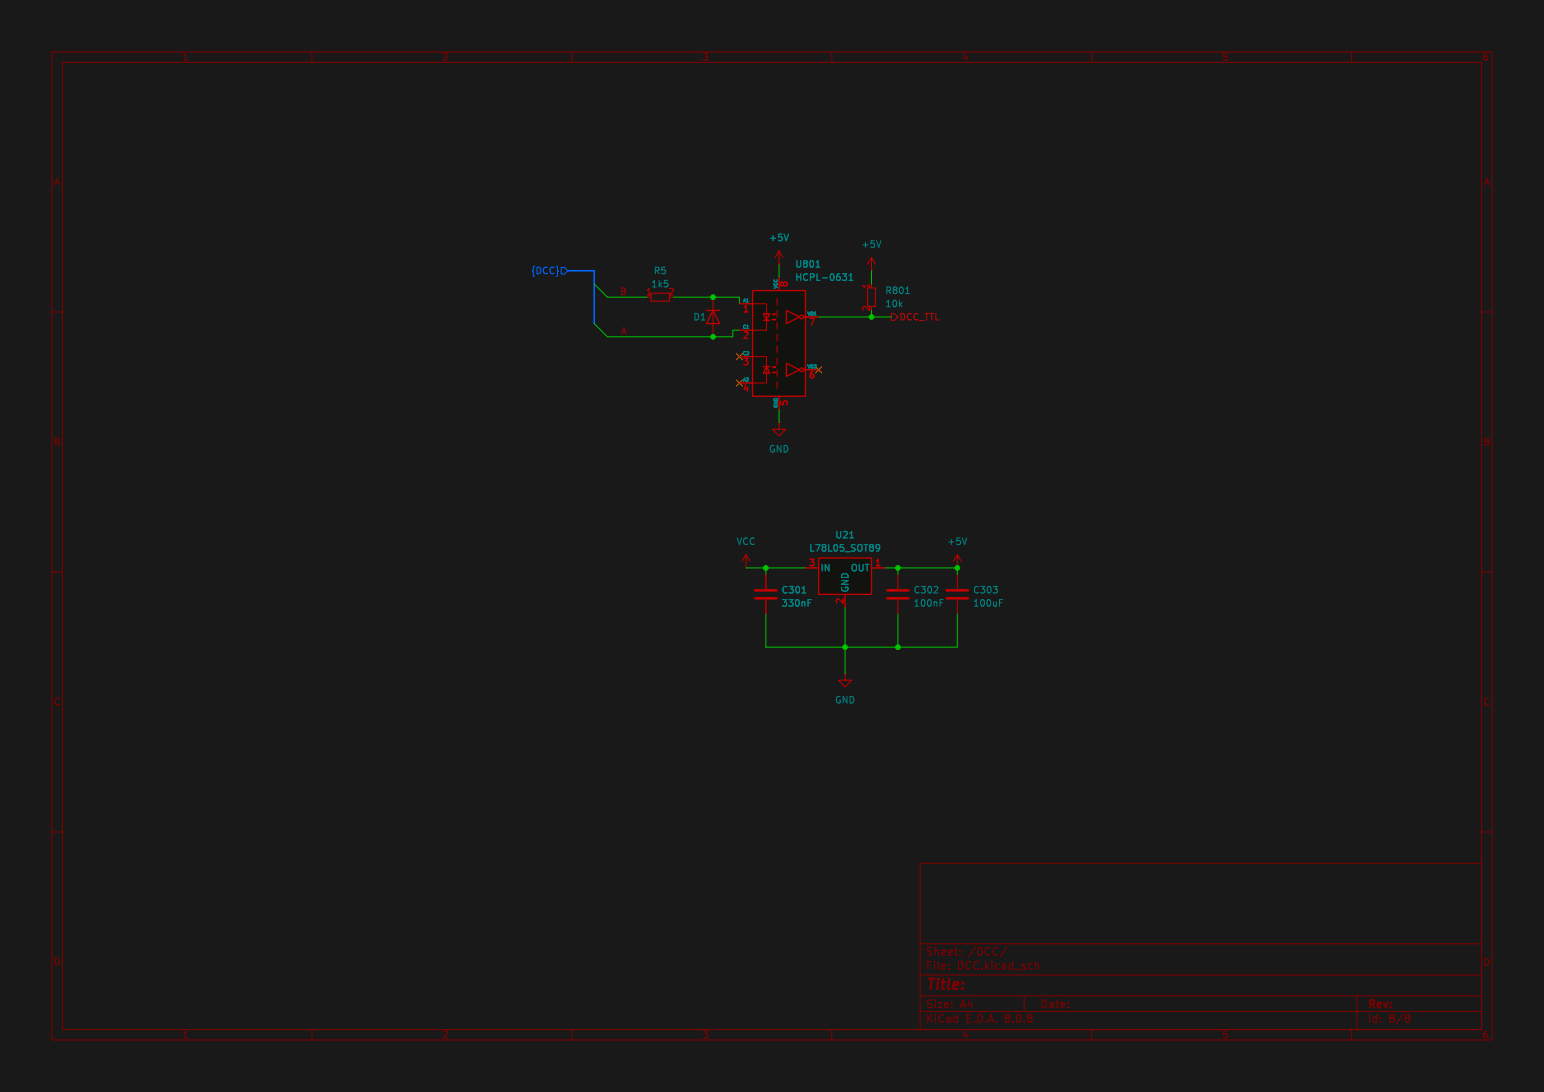
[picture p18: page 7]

Id: 8/8 Title: File: DCC.kicad_sch Sheet: /DCC/

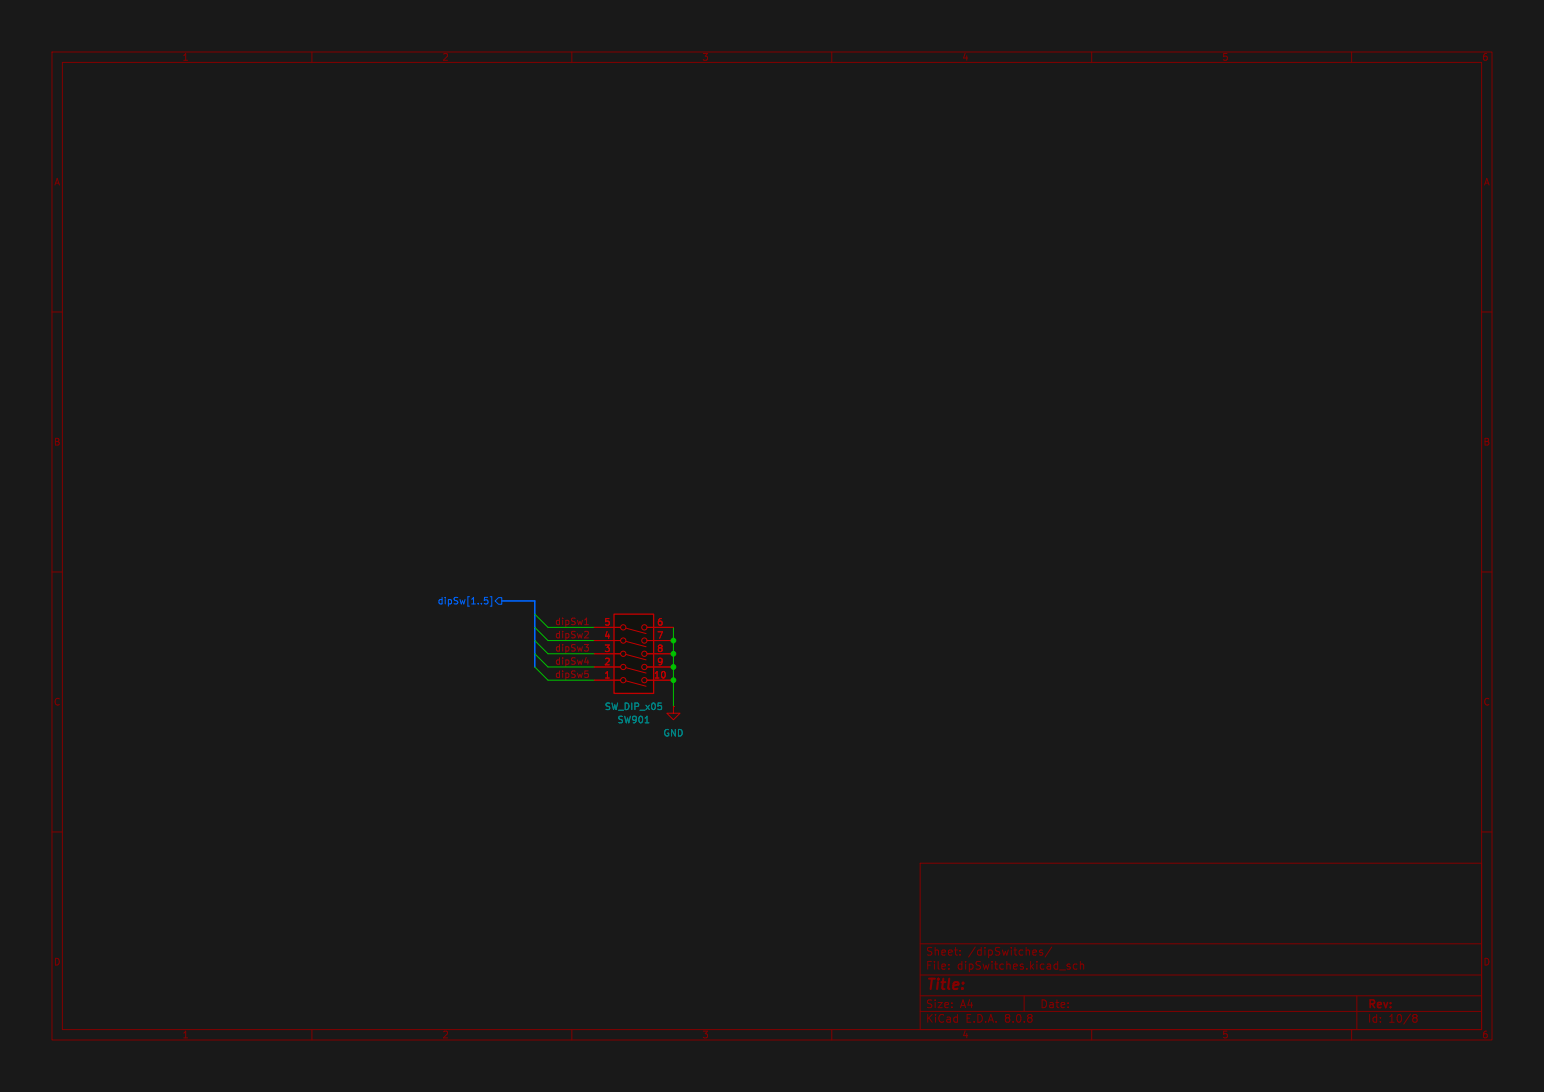
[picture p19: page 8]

Id: 10/8 Title: File: dipSwitches.kicad_sch Sheet: /dipSwitches/ GND

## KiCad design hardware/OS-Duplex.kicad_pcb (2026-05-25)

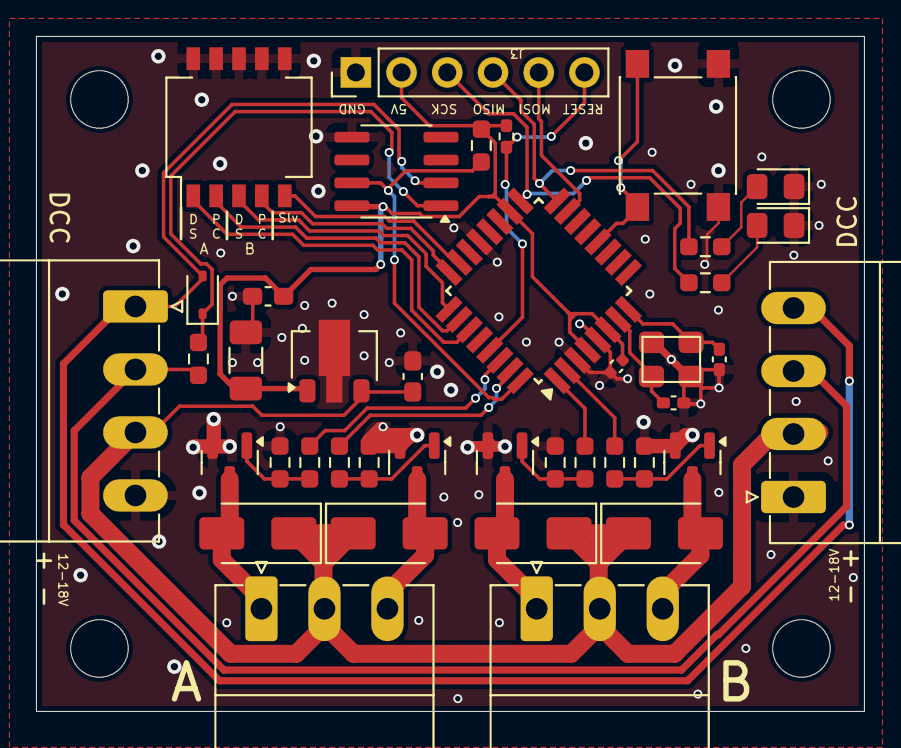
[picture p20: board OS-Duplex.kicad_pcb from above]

Board: 2 copper layers, 46.0 x 37.5 mm, 41 parts (0 on the bottom side), 33 nets.

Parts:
C1, C2: 12pF; C_0402_1005Metric_Pad0.74x0.62mm_HandSolder
C3: 100nF; C_0402_1005Metric
C301: 330nF; C_0603_1608Metric_Pad1.08x0.95mm_HandSolder
C302: 100nF; C_0603_1608Metric_Pad1.08x0.95mm_HandSolder
C303: 100uF; C_1206_3216Metric_Pad1.33x1.80mm_HandSolder
D1: D; D_SOD-323
D2, D4: LED; LED_0805_2012Metric_Pad1.15x1.40mm_HandSolder
D11, D21: SS34; D_SMA
D12, D22: D_SMA
J3: ICSP; PinHeader_1x06_P2.54mm_Vertical
J11, J21: PhoenixContact_MC_1,5_3-G-3.5_1x03_P3.50mm_Horizontal
J62, J63: Screw_Terminal_01x04; PhoenixContact_MC_1,5_4-G-3.5_1x04_P3.50mm_Horizontal
Q11, Q12, Q21, Q22: AO3400A; SOT-23
R1, R801: 10k; R_0603_smalltext
R2: 10k; R_0402_1005Metric_Pad0.72x0.64mm_HandSolder
R5: 1k5; R_0603_smalltext
R6: 6k2; R_0603_1608Metric_Pad0.98x0.95mm_HandSolder
R11, R12, R21, R22: 22R; R_0603_1608Metric_Pad0.98x0.95mm_HandSolder
R13, R14, R23, R24: 10k; R_0603_1608Metric_Pad0.98x0.95mm_HandSolder
SW1: SW_SPST; tactile_SMD_6mm
SW901: SW_DIP_x05; SW_DIP_SPSTx05_Slide_KingTek_DSHP05TS_W7.62mm_P1.27mm
U21: L78L05_SOT89; SOT-89-3
U101: ATmega328-A; TQFP-32_7x7mm_P0.8mm
U801: HCPL-0631; SOIC-8_3.9x4.9mm_P1.27mm
Y1: Crystal_GND2; crystal_arduino

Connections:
+5V: C3.1, C302.1, C303.1, J3.2, R2.1, R801.1, U21.1 (OUT), U101.4 (VCC), U101.6 (VCC), U101.18 (AVCC), U801.8 (VCC)
/DCC/A: D1.2 (A), J62.1, J63.4, U801.2 (C1)
/DCC/B: J62.2, J63.3, R5.1
/DCC/DCC_TTL: R801.2, U101.32 (PD2), U801.7 (VO1)
/atmega/1.A: R12.1, U101.2 (PD4)
/atmega/1.B: R11.1, U101.1 (PD3)
/atmega/2.A: R22.1, U101.31 (PD1)
/atmega/2.B: R21.1, U101.30 (PD0)
/atmega/LED: J3.3, R6.1, U101.17 (PB5)
/atmega/LED_BLUE: J3.4, R1.1, U101.16 (PB4)
/atmega/MOSI: J3.5, U101.15 (PB3)
/atmega/RESET: J3.6, R2.2, U101.29 (~RESET/PC6)
/atmega/X1: C1.2, U101.7 (XTAL1/PB6), Y1.1
/atmega/X2: C2.2, U101.8 (XTAL2/PB7), Y1.3
/atmega/dipSw1: SW901.5, U101.23 (PC0)
/atmega/dipSw2: SW901.4, U101.24 (PC1)
/atmega/dipSw3: SW901.3, U101.25 (PC2)
/atmega/dipSw4: SW901.2, U101.26 (PC3)
/atmega/dipSw5: SW901.1, U101.27 (PC4)
GND: C1.1, C2.1, C3.2, C301.2, C302.2, C303.2, D2.1 (K), D4.1 (K), J3.1, J62.4, J63.1, Q11.2 (S), Q12.2 (S), Q21.2 (S), Q22.2 (S), R13.1, R14.1, R23.1, R24.1, SW1.2 (B), SW901.6, SW901.7, SW901.8, SW901.9, SW901.10, U21.2 (GND), U101.3 (GND), U101.5 (GND), U101.21 (GND), U801.5 (GND), Y1.2 (GND), Y1.4 (GND)
unnamed: D1.1 (K), R5.2, U801.1 (A1)
unnamed: D2.2 (A), R1.2
unnamed: D4.2 (A), R6.2
unnamed: D11.2 (A), J11.1, Q11.3 (D)
unnamed: D12.2 (A), J11.3, Q12.3 (D)
unnamed: D21.2 (A), J21.1, Q21.3 (D)
unnamed: D22.2 (A), J21.3, Q22.3 (D)
unnamed: Q11.1 (G), R11.2, R13.2
unnamed: Q12.1 (G), R12.2, R14.2
unnamed: Q21.1 (G), R21.2, R23.2
unnamed: Q22.1 (G), R22.2, R24.2
unnamed: SW1.1 (A), U101.12 (PB0)
VCC: C301.1, D11.1 (K), D12.1 (K), D21.1 (K), D22.1 (K), J11.2, J21.2, J62.3, J63.2, U21.3 (IN)

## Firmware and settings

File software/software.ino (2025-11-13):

#include "src/macros.h"
#include "src/ST.h"
#include "src/NmraDcc.h"

const int dipSwitches[] = {1,2,3,4,5} ;
const int nDipSwitches = sizeof(  dipSwitches ) / sizeof ( dipSwitches[0] ) ;

NmraDcc     dcc ;

const int   nOutputs = 4 ;
Timer       pulseTimer[nOutputs] ;
Timer       signalTimer ;
const int   pins[nOutputs] = {6,7,8,9} ;

uint8_t     state[nOutputs] = { 0, 0, 0, 0 } ;

const int   Pulse       = 0 ;
const int   Steady      = 1 ;
const int   Double      = 0 ;
const int   Single      = 1 ;

bool        bGettingAddress ;

typedef struct Settings_
{
    uint16_t    primaryAddress ;
    uint16_t    secondaryAddress ;
    uint8_t     single_double       : 1 ;
    uint8_t     pulse_steady        : 1 ;
    uint8_t     slaved              : 1 ;
    uint8_t     isSignal           : 1 ;

} Settings ;

Settings output[2] ;

uint16_t beginAddress = 50 ;

uint8_t newValue = ;

void readDipswitches()
{
    static uint8_t  oldValue = 0xFF ;
    newValue = 0 ;

    for( int i = 0 ; i < nDipSwitches ; i ++ ) 
    {
        pinMode( dipSwitches[i], INPUT_PULLUP ) ;
        newValue |= ( digitalRead( dipSwitches[i] ) << i ) ;
    }

    if( newValue != oldValue )
    {   oldValue  = newValue ;
        
        // number1 
        // number2
        // output[0].settings.bits.single_double      = (newValue >> 0) & 1 ;
        // output[0].settings.bits.pulse_continous    = (newValue >> 1) & 1 ;
        // output[1].settings.bits.single_double      = (newValue >> 2) & 1 ;
        // output[1].settings.bits.pulse_continous    = (newValue >> 3) & 1 ;
        // output[1].settings.bits.slaved             = (newValue >> 4) & 1 ;

        calculateAddresses() ;
    }
}


extern uint16_t beginAddress ;

void calculateAddresses()
{
    // reset
    output[0].primaryAddress   = 0 ;
    output[0].secondaryAddress = 0 ;
    output[1].primaryAddress   = 0 ;
    output[1].secondaryAddress = 0 ;

    uint16_t addr = beginAddress ;

    switch( newValue & 0b11111 )
    {
        // ─────────────── S = 0 (no slave)
        case 0b10100:                               // single pulse    single pulse    S=0
        case 0b10110:                               // single pulse    single steady   S=0
        case 0b11100:                               // single steady   single pulse    S=0
        case 0b11110:                               // single steady   single steady   S=0
            // out1 single (2), out2 single (2)
            output[0].primaryAddress   = addr++ ;
            output[0].secondaryAddress = addr++ ;
            output[1].primaryAddress   = addr++ ;
            output[1].secondaryAddress = addr++ ;
            break ;

        // out1 single (2), out2 double (1)  → 3 adressen totaal
        case 0b10000:                               // single pulse    double pulse    S=0
        case 0b10010:                               // single pulse    double steady   S=0
        case 0b11000:                               // single steady   double pulse    S=0
        case 0b11010:                               // single steady   double steady   S=0
            output[0].primaryAddress   = addr++ ;
            output[0].secondaryAddress = addr++ ;
            output[1].primaryAddress   = addr++ ;
            break ;

        // out1 double (1), out2 single (2)  → 3 adressen totaal
        case 0b00100:                               // double pulse    single pulse    S=0
        case 0b00110:                               // double pulse    single steady   S=0
        case 0b01100:                               // double steady   single pulse    S=0
        case 0b01110:                               // double steady   single steady   S=0
            output[0].primaryAddress   = addr++ ;
            output[1].primaryAddress   = addr++ ;
            output[1].secondaryAddress = addr++ ;
            break ;

        // beide double (1+1)  → 2 adressen totaal
        case 0b00000:                               // double pulse    double pulse    S=0
        case 0b00010:                               // double pulse    double steady   S=0
        case 0b01000:                               // double steady   double pulse    S=0
        case 0b01010:                               // double steady   double steady   S=0
            output[0].primaryAddress   = addr++ ;
            output[1].primaryAddress   = addr++ ;
            break ;

        // ─────────────── S = 1 (slave-varianten met extra vrij relais) → 2 adressen totaal
        // (out1 double 1 adres + vrij relais 1 adres)
        case 0b00101:                               // double pulse    slave single    S=1
        case 0b01101:                               // double steady   slave single    S=1
            output[0].primaryAddress     = addr++ ;
            output[1].secondaryAddress   = addr++ ;
            break ;

        // ─────────────── S = 1 (signal / fully slaved) → 1 logisch adres
        case 0b00001:                               // double pulse    slave double    S=1
        case 0b00011:                               // double pulse    slave double    S=1
        case 0b00111:                               // double pulse    slave single    S=1
        case 0b01001:                               // double steady   slave double    S=1
        case 0b01011:                               // double steady   slave double    S=1
        case 0b01111:                               // double steady   slave single    S=1
        default: 
            output[0].primaryAddress   = addr++ ;
            break ;
    }

    //if

}


/* if output is steady, needs to be turned ON, so we need to store 4 states of 4 possible outputs.
   if output is slaved, the relay need to turned on or off
*/
void initalizeOutputs() 
{
}


void setup()
{
    for( int i = 0 ; i < nOutputs ; i ++ )
    {
        pulseTimer[i].set( TIMER_ON, 75 ) ;
    }

    Serial.begin( 115200 ) ;

    dcc.pin( 2, 0 ) ;
    dcc.init( MAN_ID_DIY, 11, FLAGS_OUTPUT_ADDRESS_MODE | FLAGS_DCC_ACCESSORY_DECODER, 0 );

    signalTimer.set( TIMER_TOGGLE, 333 ) ;
    initalizeOutputs() ;
}

void loop()
{
    readDipswitches() ;

    dcc.process() ;

    updatePulses() ;

    handleElektroFrog() ;

    handleSignal() ;
}

uint8_t aspectMask ;
uint8_t blinkMask ;

void notifyDccSigOutputState( uint16_t address, uint8_t aspect ) // incomming DCC EXT commands
{
    if( address != beginAddress ) return ;

    if( output[0].isSignal )
    {
        aspectMask   =  aspect & 0x0F ;
        blinkMask    = (aspect >> 4) & 0x0F ;
    }
}

void handleSignal() // todo for later
{
    signalTimer.update( 1 ) ;

    if( signalTimer.Q )
    {
        for( int i = 0 ; i < nOutputs ; i ++ )
        {
            const uint8_t bit = (uint8_t)(1u << i) ;
            
            if( (blinkMask & bit) != 0u ) { digitalWrite( pins[i], !  digitalRead( pins[i] )) ; }
            else                          { digitalWrite( pins[i], !!(aspectMask & bit     )) ; }
        }
    }
}

static uint8_t pointDirection ;
static uint8_t      frogState = 0 ;
void setElektroFrog( uint8_t direction )
{
    pointDirection = direction ;
    frogState = 1 ;
}

// handles both relay in combination with the pulse outpus.
void handleElektroFrog()
{
    static Timer frogTimer ;
    frogTimer.update() ;

    switch( frogState )
    {
    case 0: // idle
        
        break ;

    case 1:
        digitalWrite( pins[2], LOW ) ; // kill both array
        digitalWrite( pins[3], LOW ) ;
        frogTimer.set( TIMER_ON, 25 ) ;
        frogState ++ ;
        break ;

    case 2:
        if( frogTimer.Q )
        {
            if( pointDirection ) state[1] = 1 ; // fire up the pulse.
            else                 state[0] = 1 ; 

            frogTimer.update( 0 ) ;             // clear timer
            frogTimer.set( TIMER_ON, 100 ) ;    // reset timer
            frogState ++ ;
        }
        break ;

    case 3:
        if( frogTimer.Q )
        {
            if( pointDirection ) digitalWrite( pins[3], HIGH ) ;
            else                 digitalWrite( pins[2], HIGH ) ;
            frogState = 0 ;
        }

        break ;
    }
}

void notifyDccAccTurnoutOutput( uint16_t address, uint8_t direction, uint8_t output_ ) // incomming DCC commands
{
    if( bGettingAddress ) 
    {
        if( direction > 0 ) direction = 1 ; 
        beginAddress = address ;
        calculateAddresses() ;
        return ;
    }

    // if( mode == signal
    // ||  mode == complexPoint ) return ;

    if( direction > 0 ) direction = 1 ; 

    for( int i = 0 ; i < 2 ; i ++ ) 
    {
        if( address == output[i].primaryAddress )
        {
            if( output[i].pulse_steady == Steady )
            {
                digitalWrite( pins[i*2], direction ) ;       // happens for both single and double steady

                if( output[i].single_double == Double )    // when we are double we also inverse control the other output
                {
                    digitalWrite( pins[i*2+1], !direction ) ;
                }
                return ;
            }

            if( output[i].pulse_steady  ==  Pulse 
            &&  output[i].single_double == Double )       // we are both pulsed and double (single pulsed is not used)
            {
                if( i == 0 && output[1].slaved )
                {
                    setElektroFrog( direction ) ;
                    return ;
                }

                if( direction == 0 ) state[i*2  ] = 1 ;     // mark the pin to be pulsed 
                else                 state[i*2+1] = 1 ;     // mark the other pin to be pulsed 
                return ;
            }
        }
        if( address == output[i].secondaryAddress         // we only have a secondary address if we are a single output
        &&  output[i].pulse_steady == Steady )            // and we are not pulsed!, we dont do single pulse
        {
            digitalWrite( pins[i*2+1], direction ) ;
            return ;
        }
    }
}


void updatePulses()
{
    static int8_t  activePulse = -1;                 // -1 = none

    for( int i = 0 ; i < nOutputs ; i ++ ) 
    if( state[i] && activePulse < 0 )
    {
        digitalWrite( pins[i], HIGH );
        pulseTimer[i].IN = 1 ;
        activePulse = i;
        break;
    }
        

    if( activePulse >= 0 
    &&  pulseTimer[activePulse].update( 1 ) )
    {
        digitalWrite( pins[activePulse], LOW );
        state[activePulse] = 0;
        pulseTimer[activePulse].update( 0 );
        activePulse = -1;
    }
}

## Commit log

2025-10-27 added all files
    [CS.kicad_sch, DCC.kicad_sch, OS-Duplex.kicad_pcb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]
2025-11-14 changed LDO
    [OS-Duplex.kicad_pcb, OS-Duplex.kicad_sch, atmega.kicad_sch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]
2025-11-15 upadted readme
    [OS-Duplex.kicad_pcb, out.kicad_sch]
2026-05-24 added translations
    [DCC.kicad_sch, OS-Duplex.kicad_pcb, OS-Duplex.kicad_sch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]
2026-05-25 changed board file
    [OS-Duplex.kicad_pcb]
